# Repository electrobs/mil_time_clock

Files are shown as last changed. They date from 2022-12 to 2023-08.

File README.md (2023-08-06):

# Military Time Clock

Military Time Clock using the 89S51 microcontroller.

author: Jay Convertino

date: 2022.12.11

license: MIT (software/hardware)

IMPORTANT: No build instructions are included. All parts needed are here, you're on your own.

## Release Versions
### Current
  - v1.0.2 = Fixed time base issues with a smaller range tuning cap.

### Past
  - v1.0.1 = Sound buzz fixed with feedback bypass resistor.
  - v1.0.0 = Original Version

## Requirements
### Hardware
  - KiCad (v7.X.X)

### Software
  - sdcc compiler (4.0.0 #11528)

## Information

### Directory Listing:

  - docs
    - Datasheets: Data documents for various ICs.
    - Manual: User manual for the clock.
  - schematic: KiCad schematic of Military Time Clock, including PCB design and bill of materials.
  - model
    - FreeCAD: Any FreeCAD models used in the project.
    - Inventor: Any Autodesk Inventor 2023 models used in the project (STL included).
  - src: Any source code for the project.
    - clock_sdcc: contains make file and code for the clock project.

### Usage
  Please see the user manual on how to use the project. Build instructions really depend on how you want to build it. It uses all through hole parts and could be done with something as simple as an etch kit, PCB mill, or a PCB fab.

### Tuning
  Recommend using a platic tuning tool to adjust trimmer cap. Track the freqency at the 2.048kHz and lower pins till they all match there expected outputs (all powers of two, 1024, 512, 128 etc). Also let the device run for about 15 minutes and check. Frequency will rise by 1 to 2 hz and then stablize within the first 30 seconds, but it is wise to triple check after some time has passed.

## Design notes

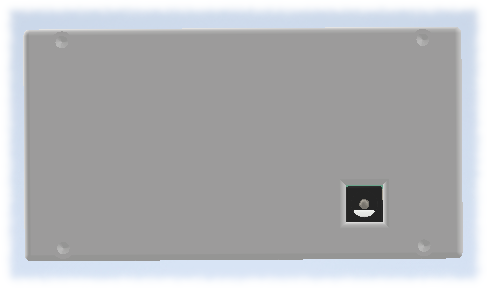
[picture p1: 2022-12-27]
model/Inventor/pics/case_rear.bmp

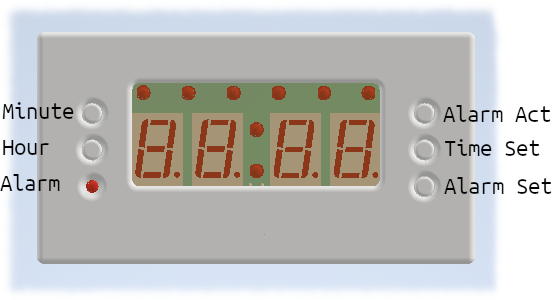
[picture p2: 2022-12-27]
model/Inventor/pics/case_front.bmp

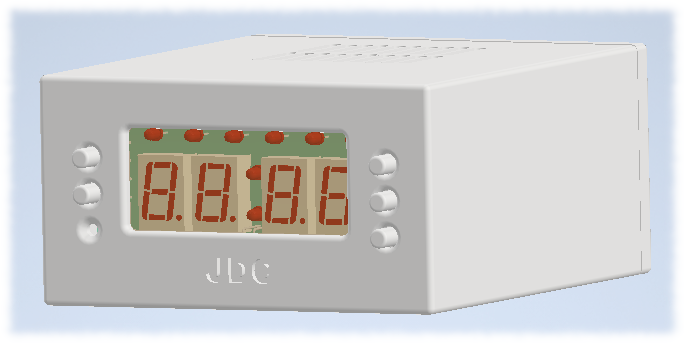
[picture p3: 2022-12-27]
model/Inventor/pics/case.bmp

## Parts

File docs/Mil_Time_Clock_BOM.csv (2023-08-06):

Date: | Tue 27 Dec 2022 05:07:47 PM EST
Component Count: | 102
Collated Components:
Item | Qty | Reference(s) | Value | Datasheet | Supplier | Manufacturer | Manufacturer Part Number | Price (Each @1) | Price (@ Quantity)
CAP CER 33PF 100V C0G/NP0 RADIAL | 1 | C1 | 33pF | https://datasheets.kyocera-avx.com/SR-Series.pdf | Digikey | KYOCERA AVX | SR151A330JAR | $0.44 | $0.44
CAP TRIMMER 2-5PF 100V TH | 1 | C2 | 6-30pF | https://media.digikey.com/pdf/Data%20Sheets/EW%20Electronics-Edmar/GKGxx015_016_Series_DS.pdf | Digikey | EW Electronics | GKG30015 | $0.97 | $0.97
CAP CER 0.1UF 100V X7S RADIAL | 14 | C3, C4, C5, C6, C7, C8, C9, C10, C17, C18, C19, C22, C23, C25 | 100nF | https://product.tdk.com/en/system/files | Digkey | TDK | FG28X7S2A104KRT06 | $0.38 | $5.32
CAP CER 18PF 100V C0G/NP0 RADIAL | 3 | C11, C12, C26 | 18pF | https://datasheets.kyocera-avx.com/SR-Series.pdf | Digkey | KYOCERA AVX | SR151A180JAR | $0.52 | $1.56
CAP ALUM 4.7UF 20% 16V RADIAL | 1 | C13 | 4.7uF | https://www.mouser.com/datasheet/2/212/KEM_A4004_ESK-1103206.pdf | Digikey | Kemet | ESK475M016AC3AA | $0.24 | $0.24
CAP CER 47PF 100V C0G RADIAL | 1 | C14 | 47nF | https://product.tdk.com/en/system/files | Digkey | TDK | FG28C0G2A470JNT06 | $0.27 | $0.27
CAP ALUM 330UF 20% 6.3V RADIAL | 2 | C15, C16 | 330uF | https://www.mouser.com/datasheet/2/212/KEM_A4004_ESK-1103206.pdf | Digikey | Kemet | ESK337M6R3AE3AA | $0.27 | $0.54
CAP CER 1000PF 100V X7R RADIAL | 1 | C20 | 1nF | https://product.tdk.com/en/system/files | Digkey | TDK | FG28X7R2A102KNT06 | $0.27 | $0.27
CAP ALUM 47UF 20% 6.3V RADIAL | 1 | C21 | 47uF | https://www.mouser.com/datasheet/2/212/KEM_A4004_ESK-1103206.pdf | Digikey | Kemet | ESK476M6R3AC3AA | $0.22 | $0.22
CAP ALUM 10UF 20% 16V RADIAL | 1 | C24 | 10uF | https://www.mouser.com/datasheet/2/212/KEM_A4004_ESK-1103206.pdf | Digikey | Kemet | ESK106M016AC3KA | $0.24 | $0.24
LED GREEN DIFFUSED 3MM ROUND T/H | 9 | D1, D2, D3, D4, D5, D6, D7, D8, D9 | LED | https://www.we-online.com/components/products/datasheet/151031VS06000.pdf | Digikey | Würth Elektronik | 151031VS06000 | $0.17 | $1.53
CONN HEADER R/A 36POS 2.54MM (CUT TO LENGTH) | 1 | J1, J4 (BOTH ARE SAME PART, BOARD TO BOARD CONNECT) | Conn_01x27 | https://multimedia.3m.com/mws/media/22446O/3mtm-100-in-pinstriphdr-295matng-length-929-series-ts0768.pdf | Digikey | 3M | 929500-01-36-RK | $3.52 | $3.52
0.1W Round Ferrite Speaker | 1 | J2 – Speaker | Speaker_Conn | https://www.jameco.com/z/45P30S-Panasonic-0-1W-Round-Ferrite-Speaker_2205561.html | Jameco | Panasonic | 45P30S | $0.69 | $0.69
DC Power Connectors Power Jack/Connector 2.1mm x 5.5mm | 1 | J3 | Barrel_Jack_Switch | https://www.gravitech.us/poja2x51.html | Mouser | Gravitech | CON-SOCJ-2155 | $1.00 | $1.00
TRANS NPN 40V 0.2A TO92-3 | 5 | Q1, Q2, Q3, Q4, Q5 | 2N3904 | https://www.onsemi.com/pdf/datasheet/pzt3904-d.pdf | Digikey | onsemi | 2N3904TFR | $0.38 | $1.90
RES 1K OHM 5% 1/4W AXIAL | 2 | R1, R2 | 1K | https://www.te.com/commerce/DocumentDelivery/DDEController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 | Digikey | TE Connectivity Passive Product | CFR16J1K0 | $0.10 | $0.20
RES 4K7 OHM 5% 1/4W AXIAL | 5 | R3, R4, R5, R6, R7 | 4k7 | https://www.te.com/commerce/DocumentDelivery/DDEController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 | Digikey | TE Connectivity Passive Product | CFR16J4K7 | $0.10 | $0.50
RES 1K OHM 5% 1/4W AXIAL | 6 | R8, R18, R30, R32, R34, R36 | 1k | https://www.te.com/commerce/DocumentDelivery/DDEController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 | Digikey | TE Connectivity Passive Product | CFR16J1K0 | $0.10 | $0.60
RES 200K OHM 5% 1/4W AXIAL | 1 | R9 | 200k | https://www.seielect.com/catalog/sei-cf_cfm.pdf | Digikey | Stackpole Electronics Inc | CF14JT200K | $0.10 | $0.10
RES 470 OHM 5% 1/4W AXIAL | 6 | R10, R11, R12, R13, R14, R21 | 470R | https://www.te.com/commerce/DocumentDelivery/DDEController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 | Digikey | TE Connectivity Passive Product | CFR16J470R | $0.10 | $0.60
RES 10M OHM 5% 1/4W AXIAL | 1 | R15 | 10M | https://www.seielect.com/catalog/sei-cf_cfm.pdf | Digikey | Stackpole Electronics Inc | CF14JT10M0 | $0.10 | $0.10
RES 1K OHM 5% 1/4W AXIAL | 1 | R16 | 1K | https://www.te.com/commerce/DocumentDelivery/DDEController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 | Digikey | TE Connectivity Passive Product | CFR16J1K0 | $0.10 | $0.10
RES 10K OHM 5% 1/4W AXIAL | 6 | R17, R20, R29, R31, R33, R35 | 10K | https://www.te.com/commerce/DocumentDelivery/DDEController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 | Digikey | TE Connectivity Passive Product | CFR16J10K | $0.10 | $0.60
RES 1K OHM 5% 1/4W AXIAL | 6 | R22, R23, R24, R25, R26, R27 | 1K | https://www.te.com/commerce/DocumentDelivery/DDEController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 | Digikey | TE Connectivity Passive Product | CFR16J1K0 | $0.10 | $0.60
RES 10 OHM 5% 1/4W AXIAL | 1 | R28 | 10R | https://www.seielect.com/catalog/sei-cf_cfm.pdf | Digikey | Stackpole Electronics Inc | CF14JT10R0 | $0.10 | $0.10
RES 100 OHM 5% 1/4W AXIAL | 7 | R37, R38, R39, R40, R41, R42, R43 | 100R | https://www.te.com/commerce/DocumentDelivery/DDEController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 | Digikey | TE Connectivity Passive Product | CFR16J100R | $0.10 | $0.70
SWITCH TACTILE SPST-NO 0.05A 12V | 5 | S1, S2, S3, S4, S5 | SPST-NO | https://sten-eswitch-13110800-production.s3.amazonaws.com/system/asset/product_line/data_sheet/144/TL1105.pdf | Digikey | E-Switch | TL1105DF160Q | $0.20 | $1.00
CONN HEADER VERT 1POS | 1 | TP1 | TestPoint | Connector Header Through Hole 1 position | Digikey | Amphenol ICC | 861400011YO2LF | $0.10 | $0.10
7 SEGMENT LED DISPLAY | 4 | U1, U2, U3, U4 | SM420561N | https://www.we-online.com/components/products/datasheet/157142V12703.pdf | Digikey | Würth Elektronik | 157142V12703 | $1.09 | $4.36
IC AMP CLASS AB MONO 700MW 8DIP | 1 | U5 | LM386 | http://www.ti.com/lit/ds/symlink/lm386.pdf | Digikey | Texas Instruments | LM386 | $1.34 | $1.34
IC MUX/DEMUX 8X1 16DIP | 1 | U6 | 74HC4051 | https://www.ti.com/general/docs/suppproductinfo.tsp?distId=10 | Digikey | Texas Instruments | CD74HC4051E | $0.78 | $0.78
IC MCU 8BIT 4KB FLASH 40DIP | 1 | U7 | AT89S51-24PU | https://ww1.microchip.com/downloads/en/DeviceDoc/doc2487.pdf | Digikey | Microchip | AT89S51-24PU | $3.63 | $3.63
IC ASYNC BIN CNTR/OSCIL 16 DIP | 1 | U9 | SN74HC4060N | https://www.ti.com/general/docs/suppproductinfo.tsp?distId=10 | Digikey | Texas Instruments | SN74HC4060N | $0.85 | $0.85
CRYSTAL 32.7680KHZ 12.5PF TH | 1 | Y1 | 32.768Khz | https://abracon.com/Resonators/AB38T.pdf | Digikey | Abracon | AB38T-32.768KHZ | $0.17 | $0.17
CRYSTAL 12.0000MHZ 18PF TH | 1 | Y2 | 12Mhz | https://www.ctscorp.com/wp-content/uploads/ATS-ATSSM.pdf | Digikey | CTS-Frequency Control | ATS120B-E | $0.36 | $0.36
AC/DC WALL MOUNT ADAPTER 5V 2.5W 2.1x5.5mm Barrel Plug | 1 | N/A | PSU | https://www.nteinc.com/acdc_adapters/adapters_01.pdf | Digikey | NTE | 57-5D-500-4 | $10.01 | $10.01
Total Cost: | $45.11

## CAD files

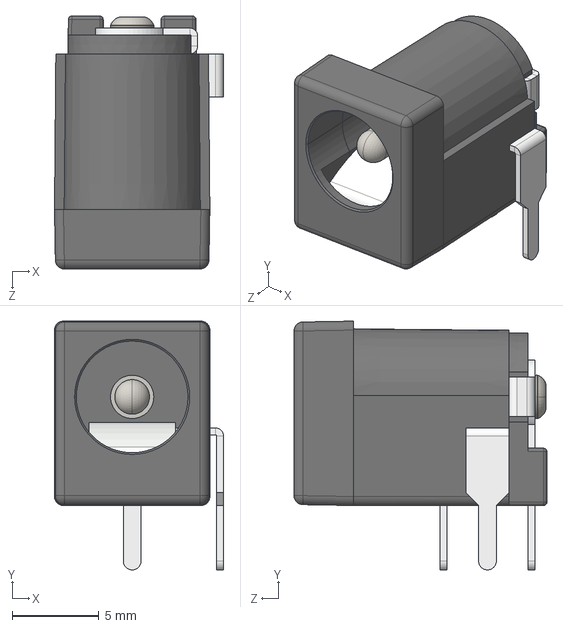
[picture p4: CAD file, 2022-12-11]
model/dc-power-jack/DC Power Jack 5.5mm x 2.1mm.STEP
9.77 x 14.4 x 14.6 mm

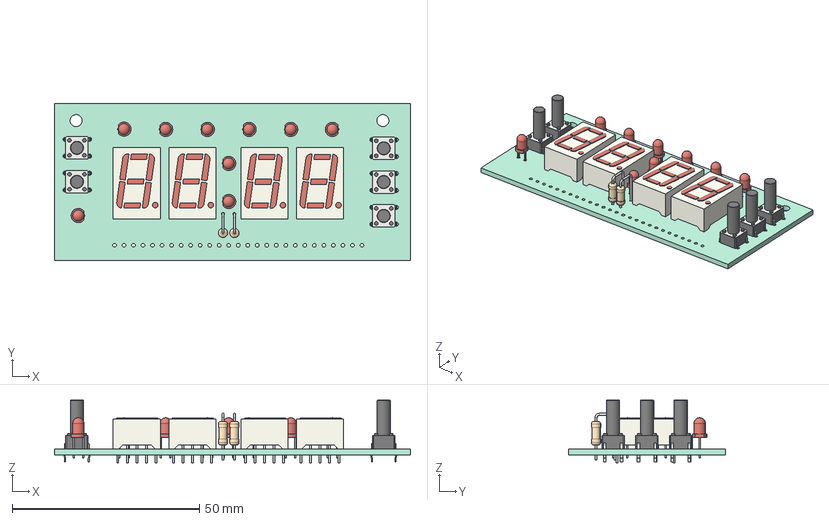
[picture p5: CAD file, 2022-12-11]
model/FreeCAD/DISPLAY_pcb-LED_DISPLAY_BOARD.step
95.0 x 41.9 x 16.8 mm
Local_CS_403d
Pcb_403d
S3_SW_PUSH_6mm_h13mm_974d04aa10fd x 5
R1_R_Axial_DIN0207_L63mm_D25mm_P508mm_Vertical_1518434c2957 x 2
U1_7SegmentLED_LTS6760_LTS6780_943fd5891115 x 4
D7_LED_D3.0mm_359ad34fe5f4 x 9

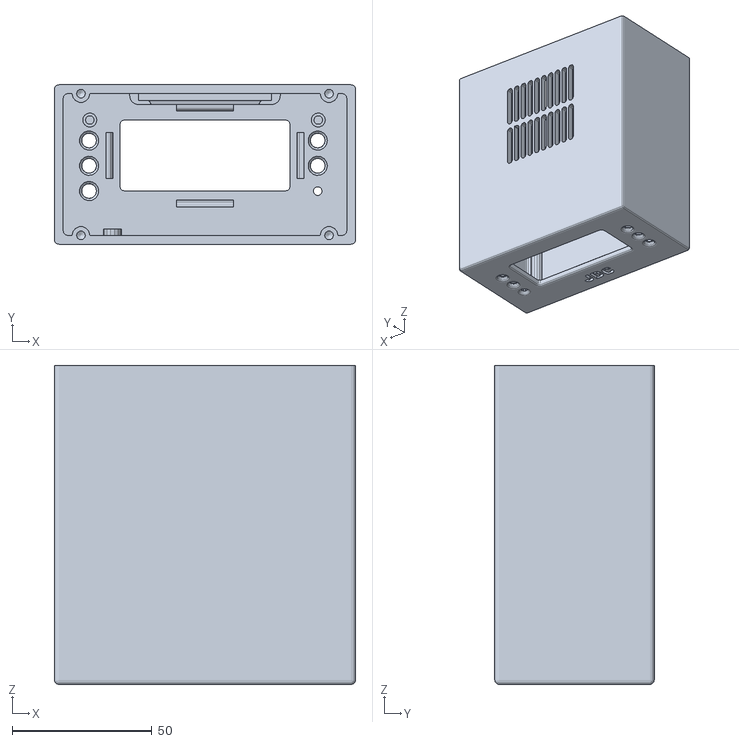
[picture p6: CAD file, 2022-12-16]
model/Inventor/Case_Front.stl
107.9 x 57.2 x 114.3

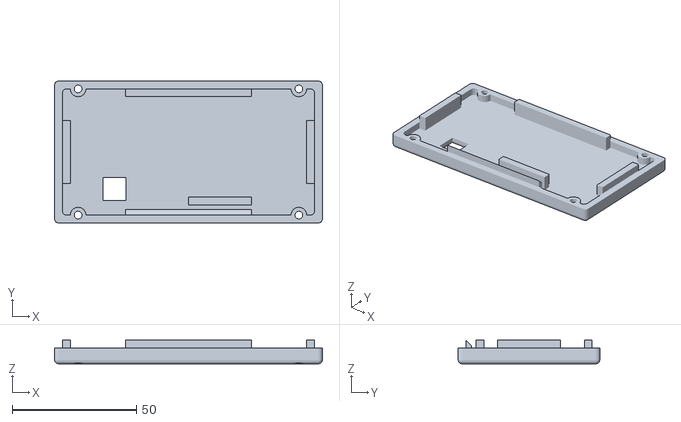
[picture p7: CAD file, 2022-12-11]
model/Inventor/Case_Rear.stl
107.9 x 57.2 x 9.52

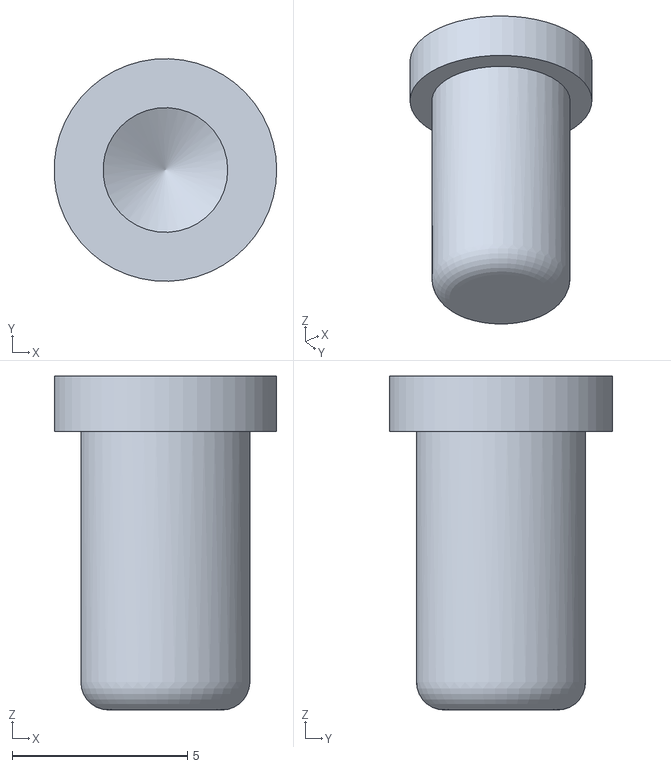
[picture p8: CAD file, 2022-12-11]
model/Inventor/button.stl
6.34 x 6.35 x 9.52

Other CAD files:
model/Inventor/CASE_ASSM/OldVersions/case.0015.iam
model/Inventor/CASE_ASSM/case.iam
model/Inventor/Case_Front.dwg
model/Inventor/Case_Front.ipt
model/Inventor/Case_Rear.dwg
model/Inventor/Case_Rear.ipt
model/Inventor/Case_lens.ipt
model/Inventor/DISPLAY_IPT/Board_Geoms_403d.iam
model/Inventor/DISPLAY_IPT/D7_LED_D3.0mm_359ad34fe5f4.ipt
model/Inventor/DISPLAY_IPT/DISPLAY_pcb-LED_DISPLAY_BOARD.iam
model/Inventor/DISPLAY_IPT/Pcb_403d.ipt
model/Inventor/DISPLAY_IPT/R1_R_Axial_DIN0207_L63mm_D25mm_P508mm_Vertical_1518434c2957.ipt
model/Inventor/DISPLAY_IPT/S3_SW_PUSH_6mm_h13mm_974d04aa10fd.ipt
model/Inventor/DISPLAY_IPT/Step_Models_403d.iam
model/Inventor/DISPLAY_IPT/Top_403d.iam
model/Inventor/DISPLAY_IPT/U1_7SegmentLED_LTS6760_LTS6780_943fd5891115.ipt
model/Inventor/MCU_IPT/Board_Geoms_bc71.iam
model/Inventor/MCU_IPT/C10_C_Disc_D30mm_W20mm_P250mm_fe13f3843ca1.ipt
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

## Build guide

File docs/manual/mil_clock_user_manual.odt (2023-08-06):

JDC

Military Time Alarm Clock

2022-12 v1.0.2


# Introduction

## Purpose

The military time alarm clock is a standard alarm clock that uses military time for the display. The clock includes one alarm that is set in military time. The clock is designed using the state-of-the-80’s hardware for user serviceability along with a full open source design under the MIT license.

Inside the clock is a 8051 micro-controller (ATMEL 89S51 variant) to power the device. This is a widely used part that is still being produced and used in multiple products as its core controller. The time base clock is a state-of-the-cmos 4060. The 4060 is a divider that has some of its unused clocks fed to a 4051 selection chip with an output to a LM386 amplifier. This gives the alarm its distinctive sound that cycles through all the tones being fed to it.

# Usage

## Setup The Clock

1. Remove the clock from its packaging.
2. Check that all the parts are included.
  - One clock
  - One 5 volt power adapter
3. Set the clock near a wall outlet that the power adapter can reach.
  - WARNING DO NOT PUT STRESS ON THE CORD.
4. Place the clock on a stable surface to prevent falling.


Figure 1.0

## First Time Power On

1. After setting up the clock, plug the power adapter into the wall.
2. Plug the barrel jack of the power adapter into the rear connector of the clock.
  - This will insert about half an inch into the device, this is normal.
  - See figure 1.0 on the previous page.
3. The clock will take approximately 2 seconds to power on.
4. Once powered on it will flash 00:00 every other second.
5. This will continue till TIME SET is pressed.
  - See figure 1.1 on the next page.
6. The clock is now ready for operation.


  Figure 1.1

## Setting The Time

1. Once the clock is powered on, time set can be performed.
2. Press and hold the TIME SET button, while performing the following actions. See figure 1.1 on previous page.
  a. Press the minute button to increment the minutes till the desired number is displayed.
    - Can be pressed and held for speed increment, tapped for single increments.
    - Minutes will roll over from 59 to 0 and will not increment hours.
  b. Press the hour button to increment the hours till the desired number is displayed.
    - Can be pressed and held for speed increment, tapped for single increments.
    - Hours will roll over from 23 to 0.
3. Let go of the TIME SET button to complete time set.

## Sync Time

  To sync the time with another clock follow this procedure.
    1. Set the time to one minute ahead of the clock you would like to sync to.
    2. Hold the TIME SET button till the clock to sync to changes to that minute, and let go.
      - The clock will start from 0 seconds (seconds are reset) whenever TIME SET is pressed.

## Setting The Alarm

1. With the time set, the alarm can be set in a similar manner.
2. Press and hold the ALARM SET button, while performing the following actions. See figure 1.1 on page 7.
  a. Press the minute button to increment the minutes till the desired number is displayed.
    - Can be pressed and held for speed increment, tapped for single increments.
    - Minutes will roll over from 59 to 0 and will not increment hours.
  b. Press the hour button to increment the hours till the desired number is displayed.
    - Can be pressed and held for speed increment, tapped for single increments.
    - Hours will roll over from 23 to 0.
3. Let go of the ALARM SET button to complete alarm set.

## Activating The Alarm

  The alarm is activated by pressing the ALARM ACT button.
  - See figure 1.1 on page 7.
  - Pressing and holding will only toggle the alarm once.
  - When the alarm LED is on, the alarm is on.
  - When the alarm LED is off, the alarm is off.

## Alarm Duration

When the alarm is reached, it will stay active for one minute without intervention. Alarm can be shut off early by pressing the ALARM ACT button.

# Technical Data

## Specifications

- POWER: 5 volt DC at 500 mA max. Center Positive.
- Audio output: 325 mW Max
- Time Display: Green 7 segment LED, with 6 Binary seconds LED (0 to 59)
- Micro-controller: 89S51
- Case: ABS Plastic

## Schematic

The following pages contain the schematic for the device.

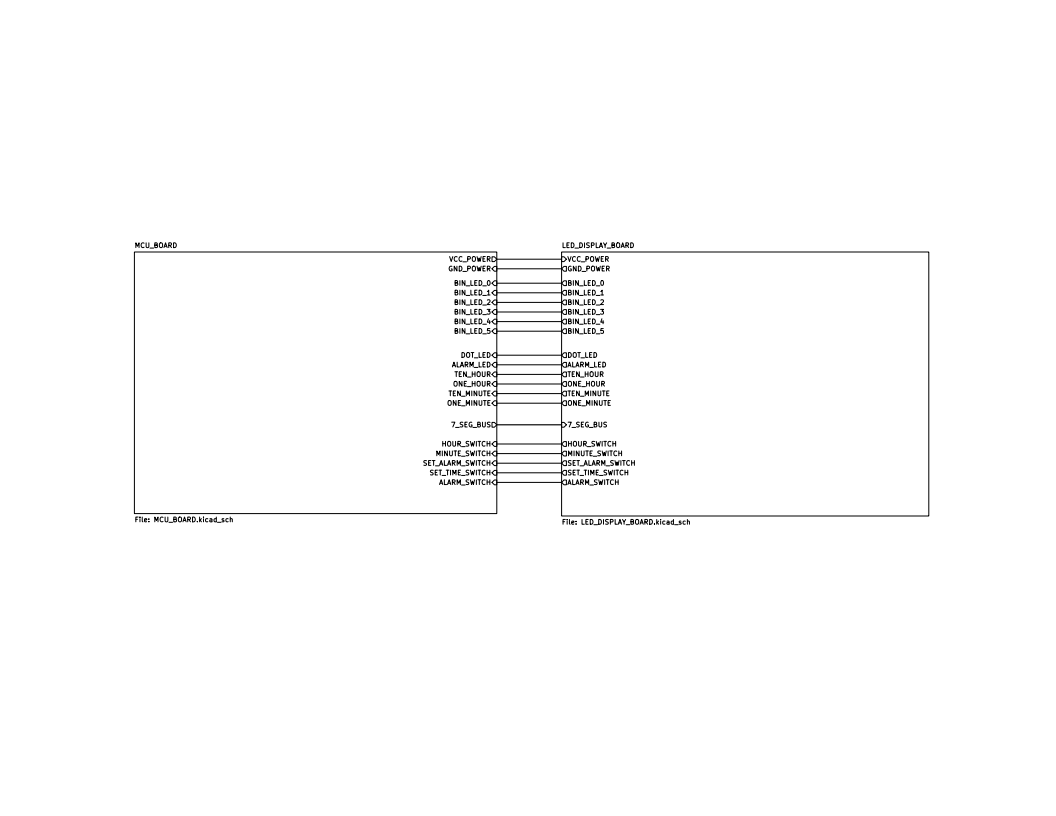
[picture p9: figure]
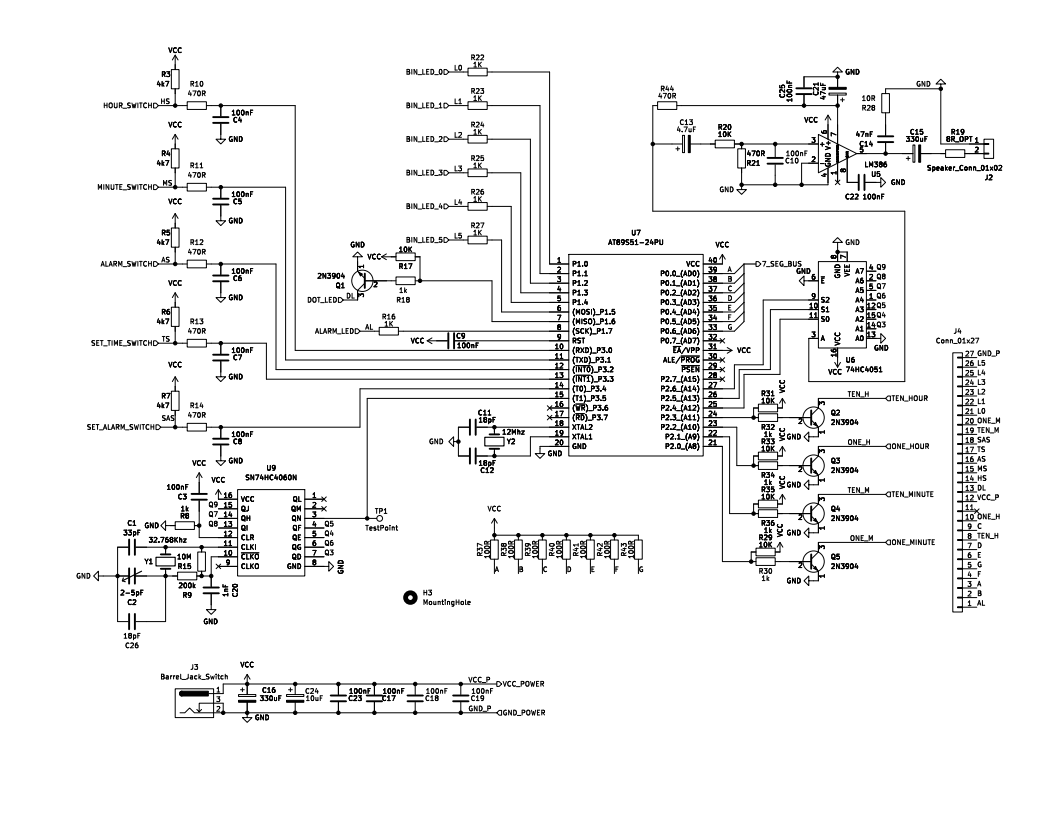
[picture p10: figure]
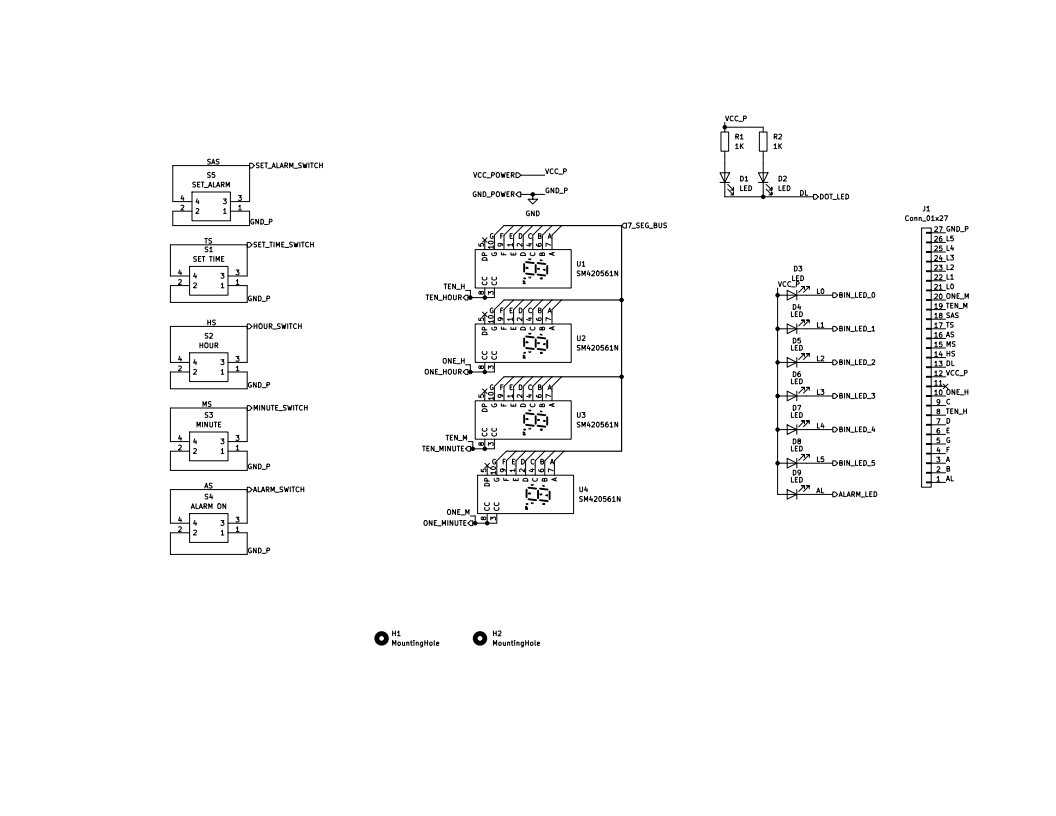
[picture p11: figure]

## CAD

The following pages contain the CAD for the device. Dimensions are not complete, and all are in inches.

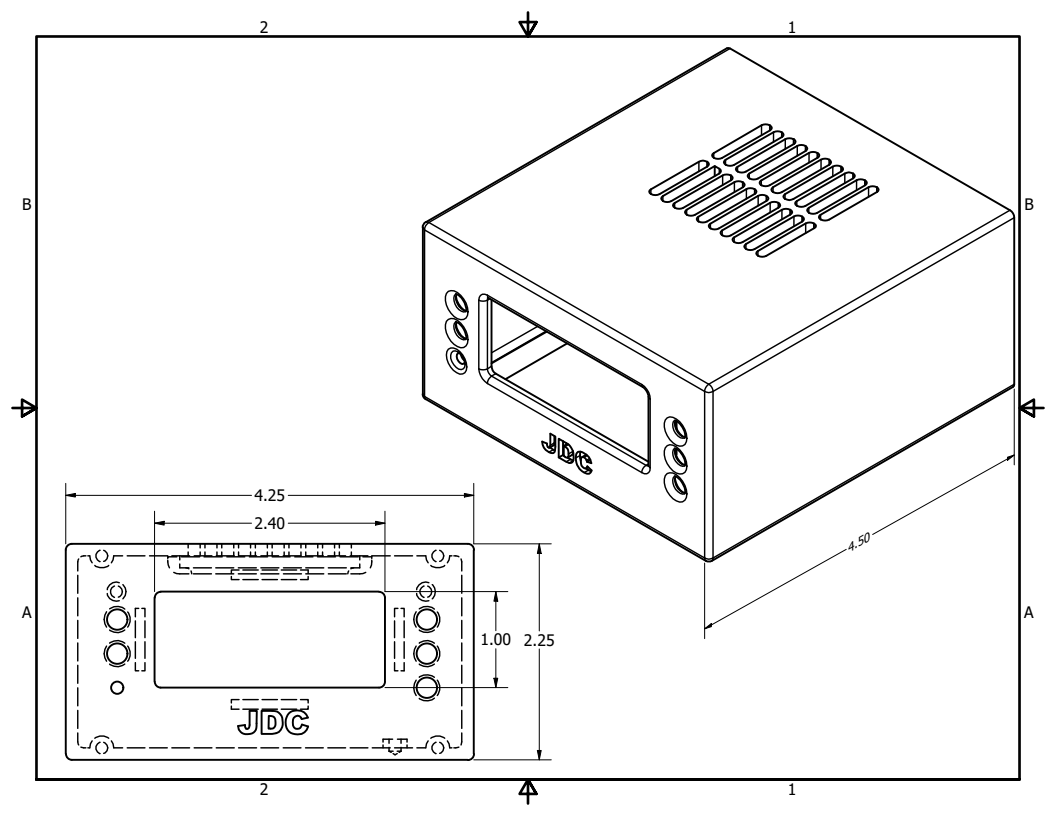
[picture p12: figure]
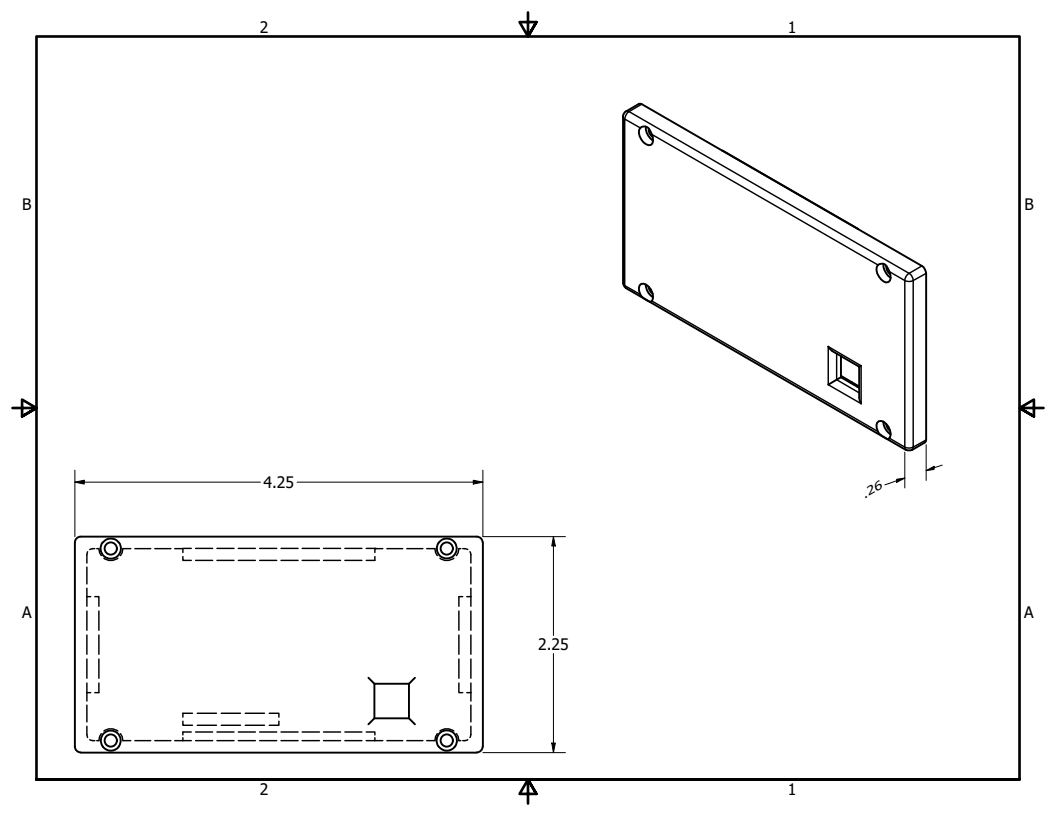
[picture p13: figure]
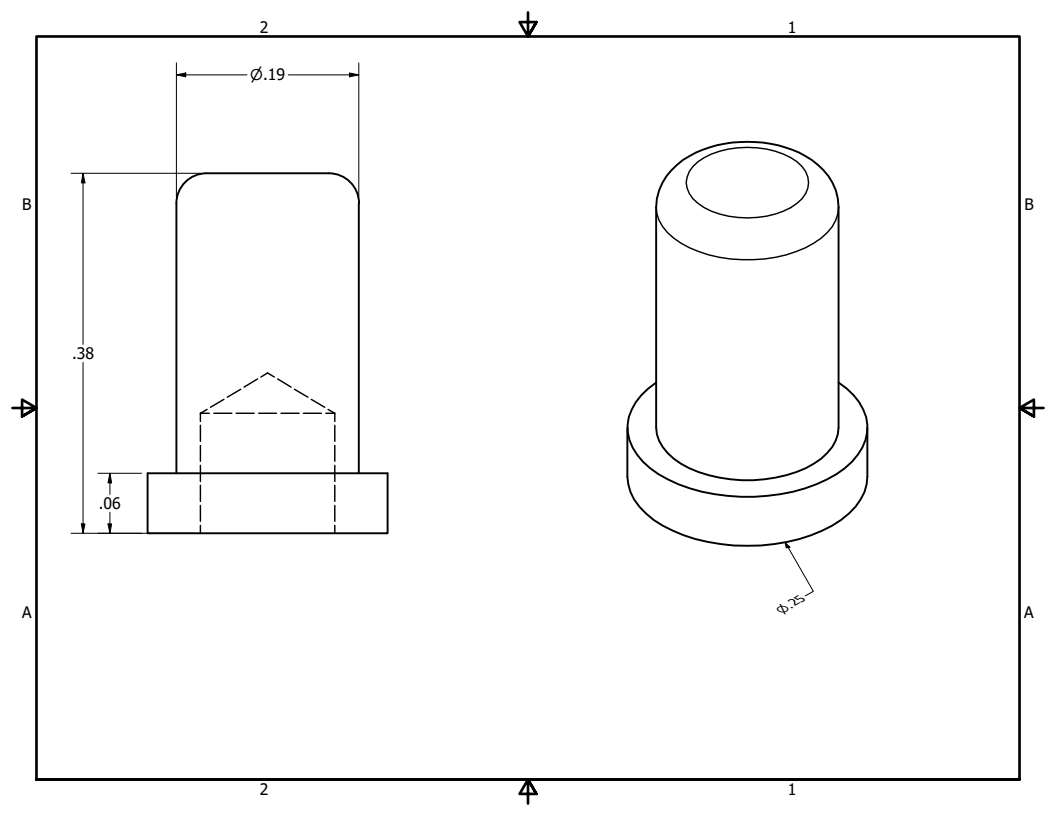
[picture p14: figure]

## Code

The following pages contain the C code for the device. They are sideways for proper formatting.

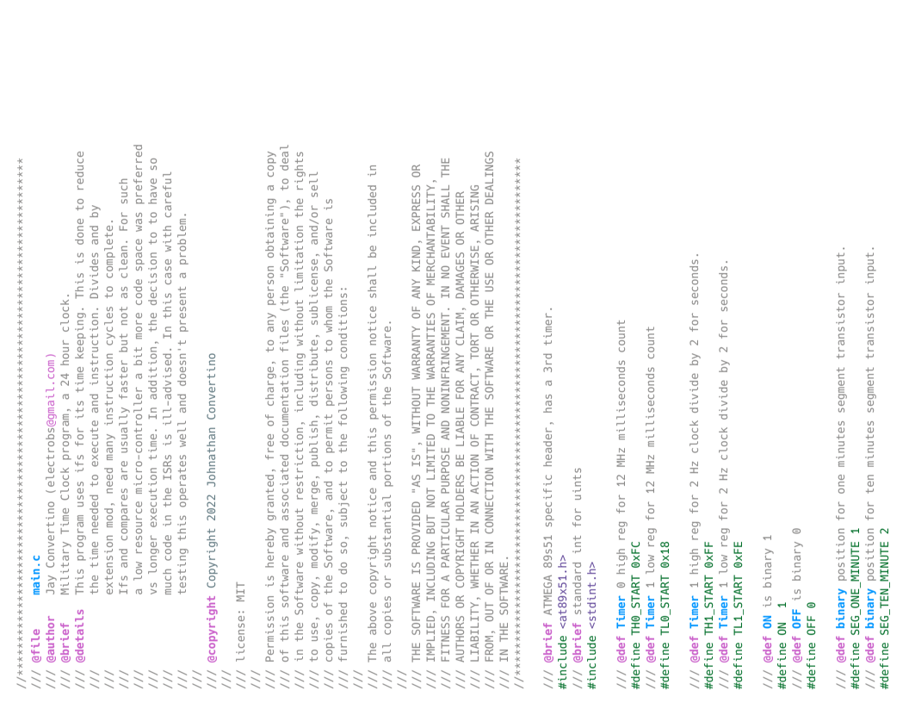
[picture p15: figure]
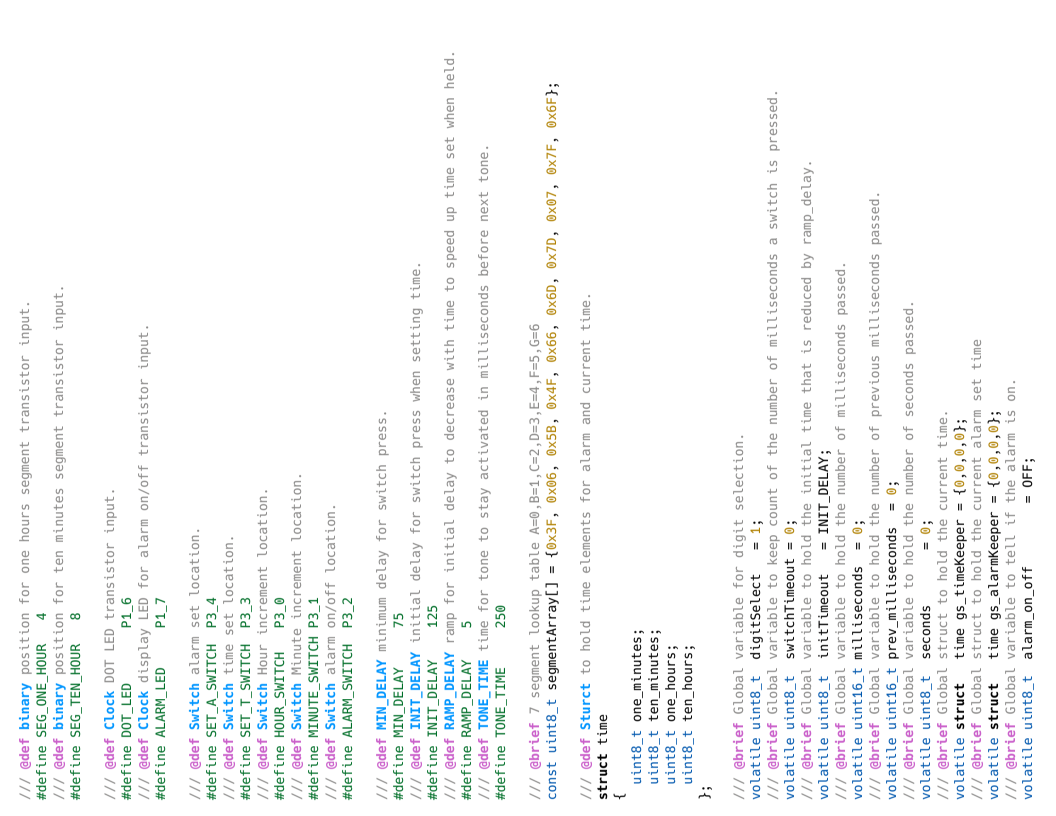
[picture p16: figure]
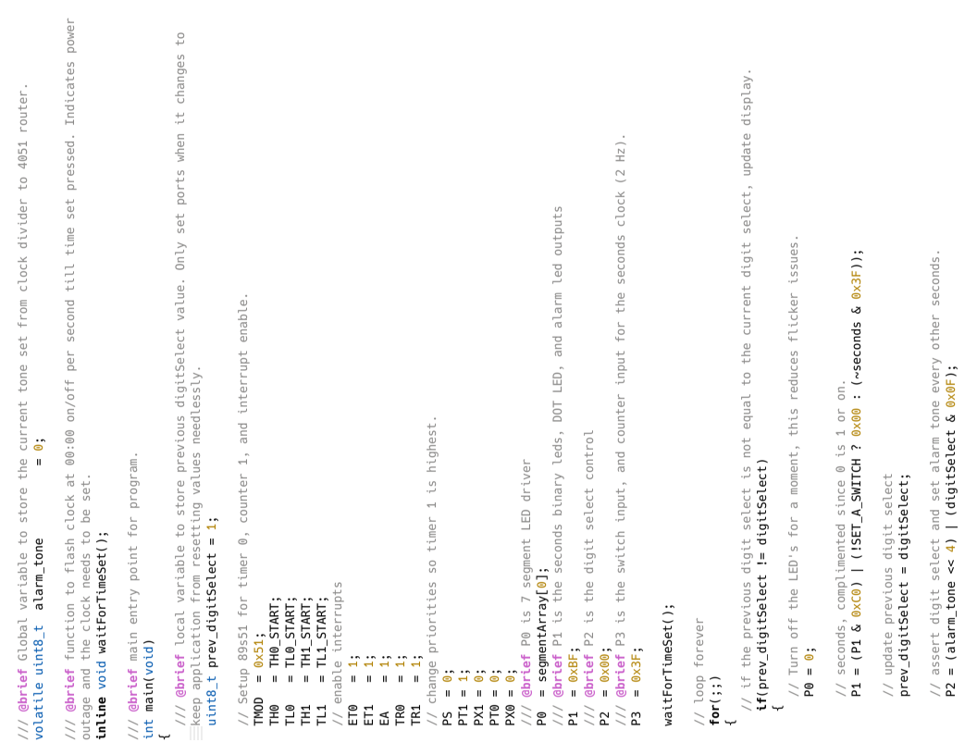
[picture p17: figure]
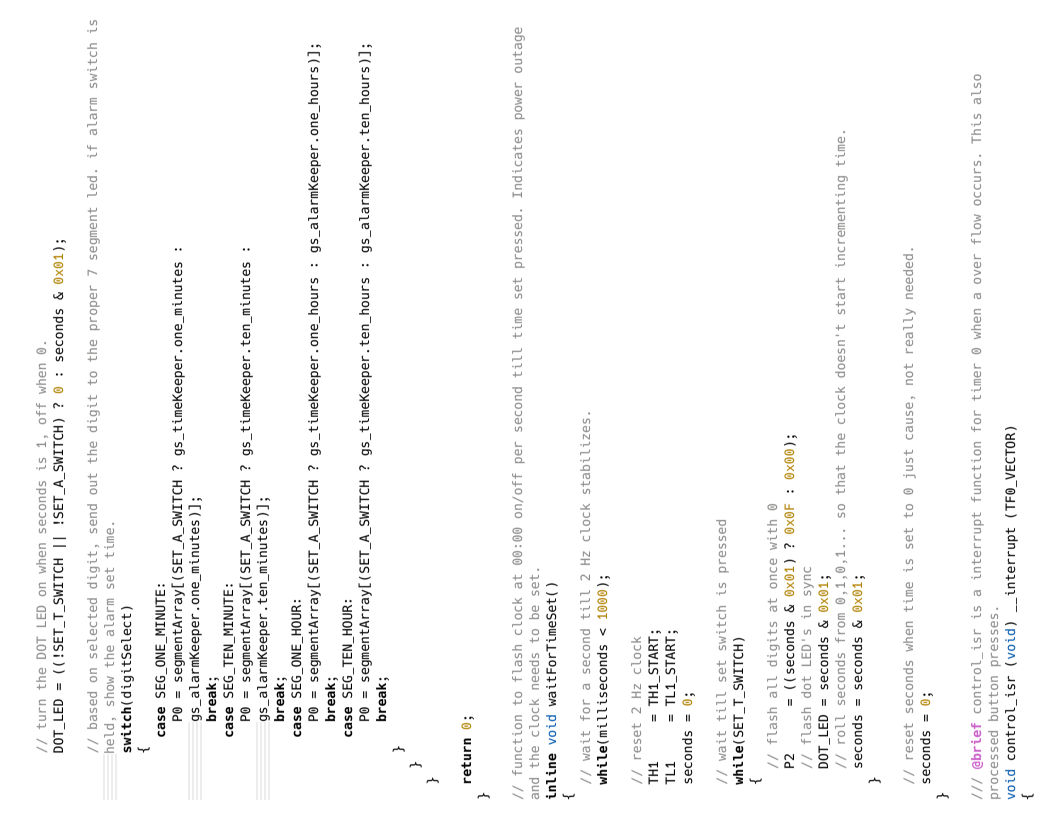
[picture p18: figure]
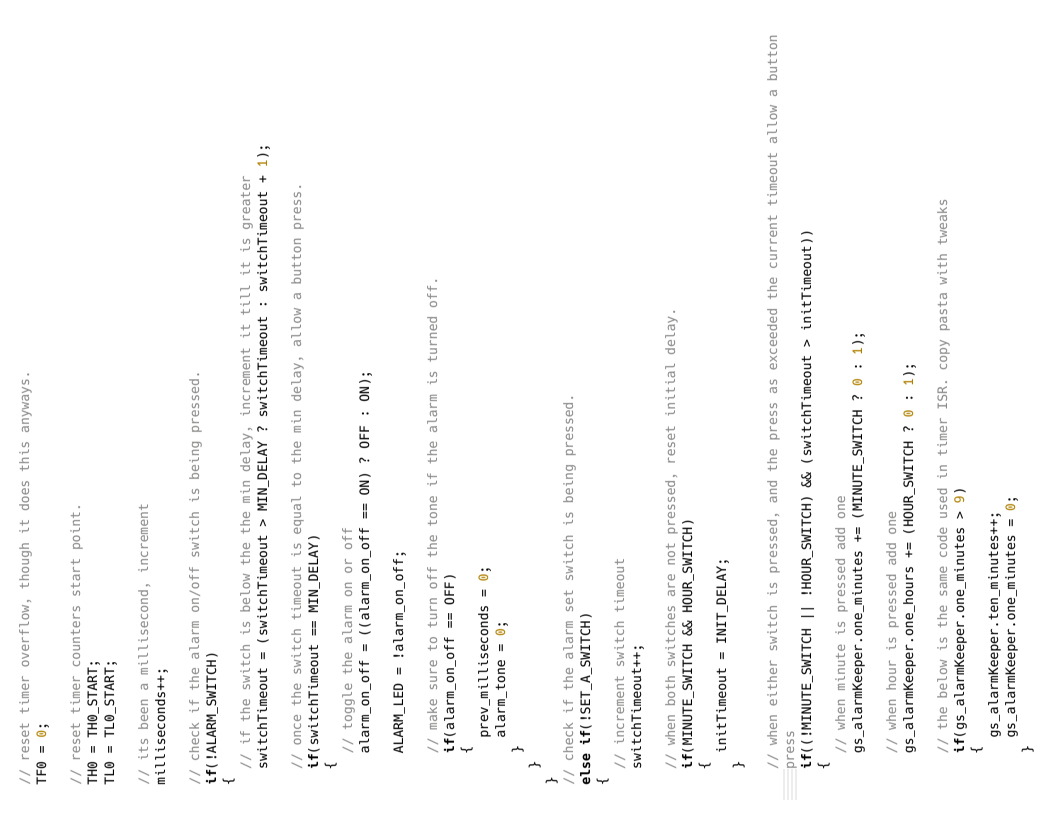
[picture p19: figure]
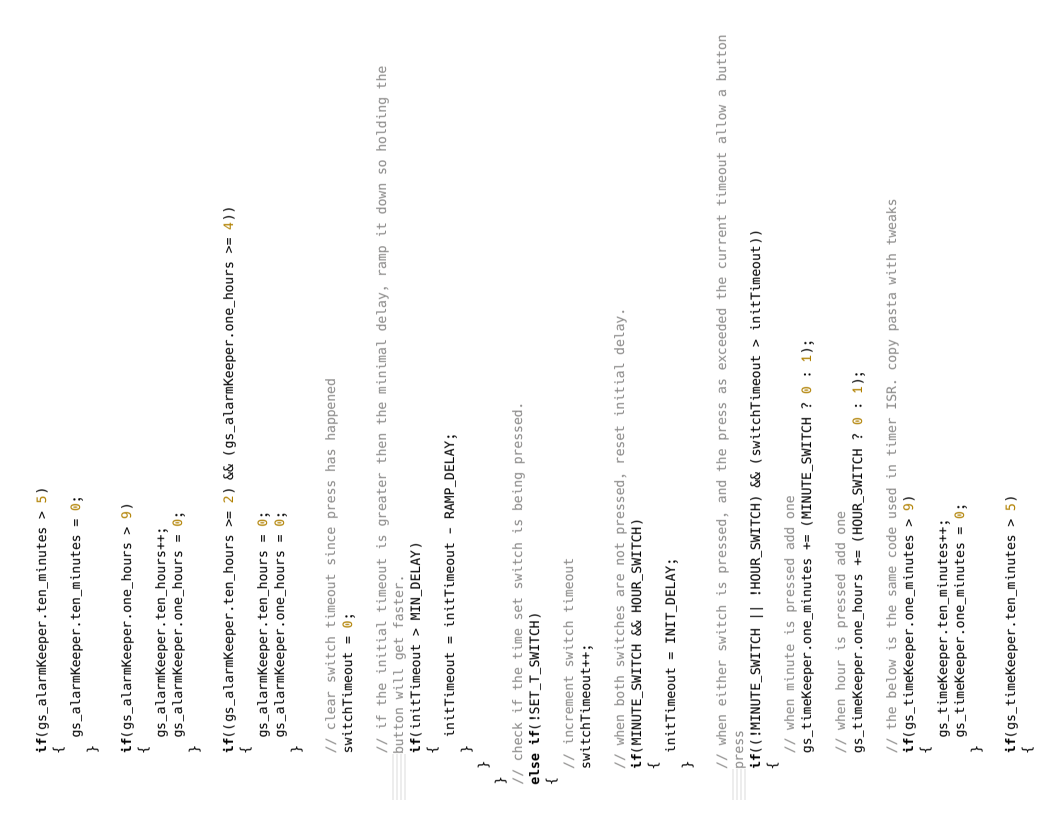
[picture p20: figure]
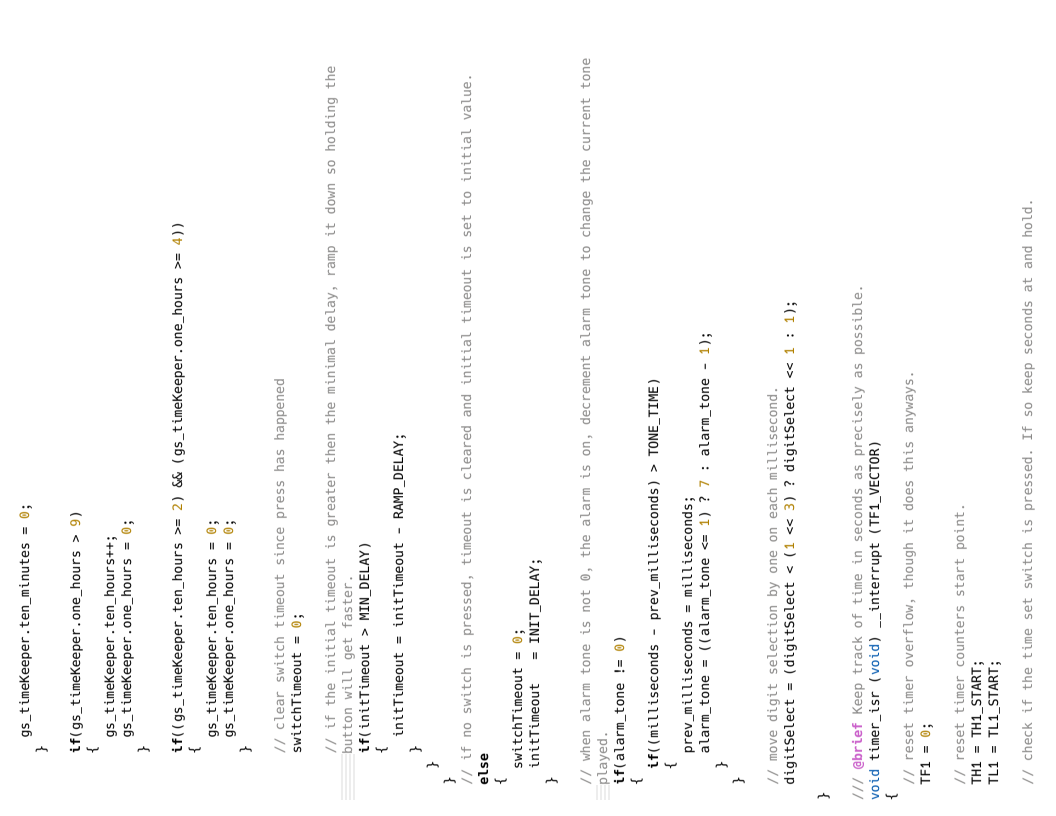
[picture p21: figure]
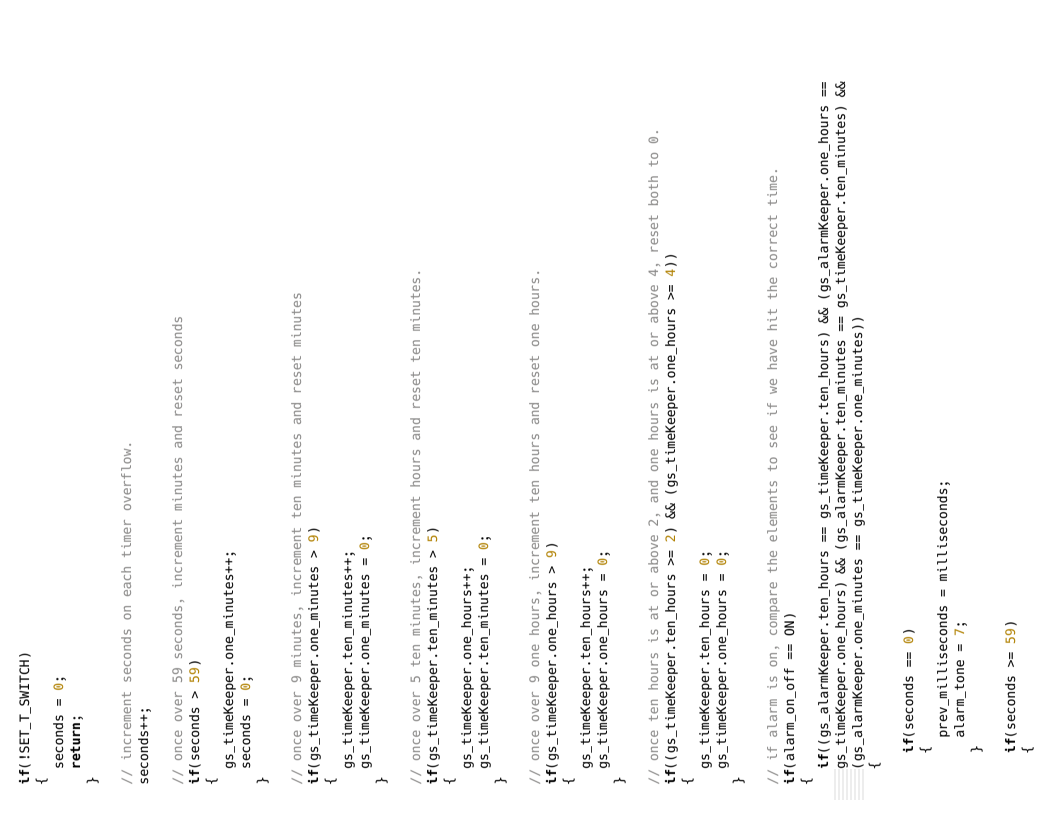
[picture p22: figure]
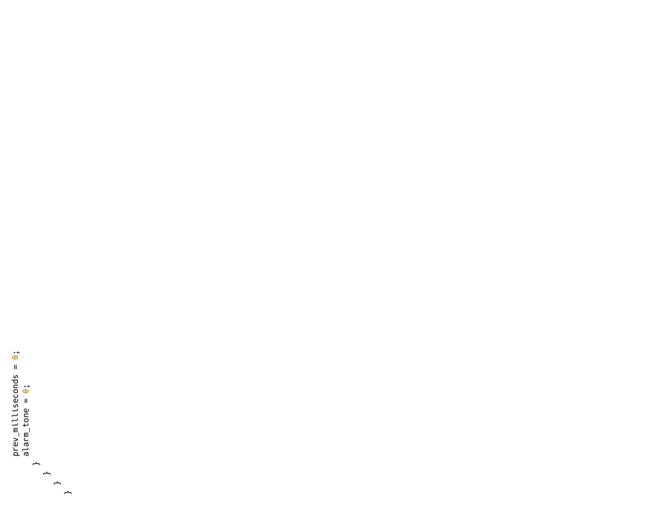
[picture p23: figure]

JDC

Military Time Alarm Clock

2022-12

v1.0.2

Change Log:

v1.0.2 = Fixed time base issues with a smaller range tuning cap.

v1.0.1 = Sound buzz fixed with feedback bypass resistor.

v1.0.0 = Original Version

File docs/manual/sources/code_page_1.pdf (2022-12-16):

//*****************************************************************************
/// @file | main.c
/// @author | Jay Convertino (electrobs@gmail.com)
/// @brief | Military Time Clock program, a 24 hour clock.
/// @details This program uses ifs for its time keeping. This is done to reduce
/// | the time needed to execute and instruction. Divides and by
/// | extension mod, need many instruction cycles to complete.
/// | Ifs and compares are usually faster but not as clean. For such
/// | a low resource micro-controller a bit more code space was preferred
/// | vs longer execution time. In addition, the decision to to have so
/// | much code in the ISRs is ill-advised. In this case with careful
/// | testing this operates well and doesn't present a problem.
///
/// @copyright Copyright 2022 Johnathan Convertino
///
/// license: MIT
///
/// Permission is hereby granted, free of charge, to any person obtaining a copy /// of this software and associated documentation files (the "Software"), to deal /// in the Software without restriction, including without limitation the rights /// to use, copy, modify, merge, publish, distribute, sublicense, and/or sell /// copies of the Software, and to permit persons to whom the Software is
/// furnished to do so, subject to the following conditions:
///
/// The above copyright notice and this permission notice shall be included in /// all copies or substantial portions of the Software.
///
/// THE SOFTWARE IS PROVIDED "AS IS", WITHOUT WARRANTY OF ANY KIND, EXPRESS OR /// IMPLIED, INCLUDING BUT NOT LIMITED TO THE WARRANTIES OF MERCHANTABILITY, /// FITNESS FOR A PARTICULAR PURPOSE AND NONINFRINGEMENT. IN NO EVENT SHALL THE /// AUTHORS OR COPYRIGHT HOLDERS BE LIABLE FOR ANY CLAIM, DAMAGES OR OTHER
/// LIABILITY, WHETHER IN AN ACTION OF CONTRACT, TORT OR OTHERWISE, ARISING /// FROM, OUT OF OR IN CONNECTION WITH THE SOFTWARE OR THE USE OR OTHER DEALINGS /// IN THE SOFTWARE.
//*****************************************************************************

/// @brief ATMEGA 89s51 specific header, has a 3rd timer.
#include <at89x51.h>

/// @brief standard int for uints
#include <stdint.h>

/// @def Timer 0 high reg for 12 MHz milliseconds count #define TH0_START 0xFC
/// @def Timer 1 low reg for 12 MHz milliseconds count
#define TL0_START 0x18

/// @def Timer 1 high reg for 2 Hz clock divide by 2 for seconds. #define TH1_START 0xFF
/// @def Timer 1 low reg for 2 Hz clock divide by 2 for seconds. #define TL1_START 0xFE

/// @def ON is binary 1
#define ON 1

/// @def OFF is binary 0
#define OFF 0

/// @def binary position for one minutes segment transistor input. #define SEG_ONE_MINUTE 1
/// @def binary position for ten minutes segment transistor input. #define SEG_TEN_MINUTE 2

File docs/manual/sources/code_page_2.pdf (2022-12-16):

/// @def binary position for one hours segment transistor input. #define SEG_ONE_HOUR 4
/// @def binary position for ten minutes segment transistor input. #define SEG_TEN_HOUR 8

/// @def Clock DOT LED transistor input.
#define DOT_LED | P1_6

/// @def Clock display LED for alarm on/off transistor input. #define ALARM_LED P1_7

/// @def Switch alarm set location.
#define SET_A_SWITCH P3_4

/// @def Switch time set location. #define SET_T_SWITCH P3_3
/// @def Switch Hour increment location. #define HOUR_SWITCH P3_0
/// @def Switch Minute increment location. #define MINUTE_SWITCH P3_1
/// @def Switch alarm on/off location.
#define ALARM_SWITCH P3_2

/// @def MIN_DELAY minimum delay for switch press.
#define MIN_DELAY 75

/// @def INIT_DELAY initial delay for switch press when setting time.
#define INIT_DELAY 125

/// @def RAMP_DELAY ramp for initial delay to decrease with time to speed up time set when held. #define RAMP_DELAY 5
/// @def TONE_TIME time for tone to stay activated in milliseconds before next tone.
#define TONE_TIME 250

/// @brief 7 segment lookup table A=0,B=1,C=2,D=3,E=4,F=5,G=6
const uint8_t segmentArray[] = {0x3F, 0x06, 0x5B, 0x4F, 0x66, 0x6D, 0x7D, 0x07, 0x7F, 0x6F};

/// @def Sturct to hold time elements for alarm and current time.
struct time
{
uint8_t one_minutes;
uint8_t ten_minutes;
uint8_t one_hours;
uint8_t ten_hours;
};

/// @brief Global variable for digit selection.
volatile uint8_t digitSelect = 1;
/// @brief Global variable to keep count of the number of milliseconds a switch is pressed. volatile uint8_t switchTimeout = 0;
/// @brief Global variable to hold the initial time that is reduced by ramp_delay. volatile uint8_t initTimeout = INIT_DELAY;
/// @brief Global variable to hold the number of milliseconds passed.
volatile uint16_t milliseconds = 0;
/// @brief Global variable to hold the number of previous milliseconds passed. volatile uint16_t prev_milliseconds = 0;
/// @brief Global variable to hold the number of seconds passed.
volatile uint8_t seconds | = 0;
/// @brief Global struct to hold the current time.
volatile struct time gs_timeKeeper = {0,0,0,0};
/// @brief Global struct to hold the current alarm set time volatile struct time gs_alarmKeeper = {0,0,0,0};
/// @brief Global variable to tell if the alarm is on.
volatile uint8_t alarm_on_off | = OFF;

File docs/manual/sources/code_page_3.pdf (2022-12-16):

/// @brief Global variable to store the current tone set from clock divider to 4051 router.
volatile uint8_t alarm_tone | = 0;

/// @brief function to flash clock at 00:00 on/off per second till time set pressed. Indicates power outage and the clock needs to be set.
inline void waitForTimeSet();

/// @brief main entry point for program.
int main(void)
{
/// @brief local variable to store previous digitSelect value. Only set ports when it changes to keep application from resetting values needlessly.
uint8_t prev_digitSelect = 1;

// Setup 89s51 for timer 0, counter 1, and interrupt enable.
TMOD = 0x51;
TH0 | = TH0_START;
TL0 | = TL0_START;
TH1 | = TH1_START;
TL1 | = TL1_START;
// enable interrupts
ET0 | = 1;
ET1 | = 1;
EA | = 1;
TR0 | = 1;
TR1 | = 1;
// change priorities so timer 1 is highest. PS = 0;
PT1 = 1;
PX1 = 0;
PT0 = 0;
PX0 = 0;
/// @brief P0 is 7 segment LED driver
P0 = segmentArray[0];
/// @brief P1 is the seconds binary leds, DOT LED, and alarm led outputs P1 = 0xBF;
/// @brief P2 is the digit select control
P2 = 0x00;
/// @brief P3 is the switch input, and counter input for the seconds clock (2 Hz). P3 = 0x3F;

waitForTimeSet();

// loop forever
for(;;)
{
// if the previous digit select is not equal to the current digit select, update display. if(prev_digitSelect != digitSelect)
{
// Turn off the LED's for a moment, this reduces flicker issues.
P0 = 0;

// seconds, complimented since 0 is 1 or on.
P1 = (P1 & 0xC0) | (!SET_A_SWITCH ? 0x00 : (~seconds & 0x3F));

// update previous digit select
prev_digitSelect = digitSelect;

// assert digit select and set alarm tone every other seconds.
P2 = (alarm_tone << 4) | (digitSelect & 0x0F);

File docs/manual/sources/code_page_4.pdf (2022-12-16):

// turn the DOT LED on when seconds is 1, off when 0.
DOT_LED = ((!SET_T_SWITCH || !SET_A_SWITCH) ? 0 : seconds & 0x01);

// based on selected digit, send out the digit to the proper 7 segment led. if alarm switch is held, show the alarm set time.
switch(digitSelect)
{
case SEG_ONE_MINUTE:
P0 = segmentArray[(SET_A_SWITCH ? gs_timeKeeper.one_minutes : gs_alarmKeeper.one_minutes)];
break;
case SEG_TEN_MINUTE:
P0 = segmentArray[(SET_A_SWITCH ? gs_timeKeeper.ten_minutes : gs_alarmKeeper.ten_minutes)];
break;
case SEG_ONE_HOUR:
P0 = segmentArray[(SET_A_SWITCH ? gs_timeKeeper.one_hours : gs_alarmKeeper.one_hours)]; break;
case SEG_TEN_HOUR:
P0 = segmentArray[(SET_A_SWITCH ? gs_timeKeeper.ten_hours : gs_alarmKeeper.ten_hours)]; break;
}
}
}

return 0;
}

// function to flash clock at 00:00 on/off per second till time set pressed. Indicates power outage and the clock needs to be set.
inline void waitForTimeSet()
{
// wait for a second till 2 Hz clock stabilizes. while(milliseconds < 1000);

// reset 2 Hz clock
TH1 | = TH1_START;
TL1 | = TL1_START;
seconds = 0;

// wait till set switch is pressed while(SET_T_SWITCH)
{
// flash all digits at once with 0
P2 | = ((seconds & 0x01) ? 0x0F : 0x00);
// flash dot LED's in sync
DOT_LED = seconds & 0x01;
// roll seconds from 0,1,0,1... so that the clock doesn't start incrementing time. seconds = seconds & 0x01;
}

// reset seconds when time is set to 0 just cause, not really needed.
seconds = 0;
}

/// @brief control_isr is a interrupt function for timer 0 when a over flow occurs. This also processed button presses.
void control_isr (void) __interrupt (TF0_VECTOR)
{

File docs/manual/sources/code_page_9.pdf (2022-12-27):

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
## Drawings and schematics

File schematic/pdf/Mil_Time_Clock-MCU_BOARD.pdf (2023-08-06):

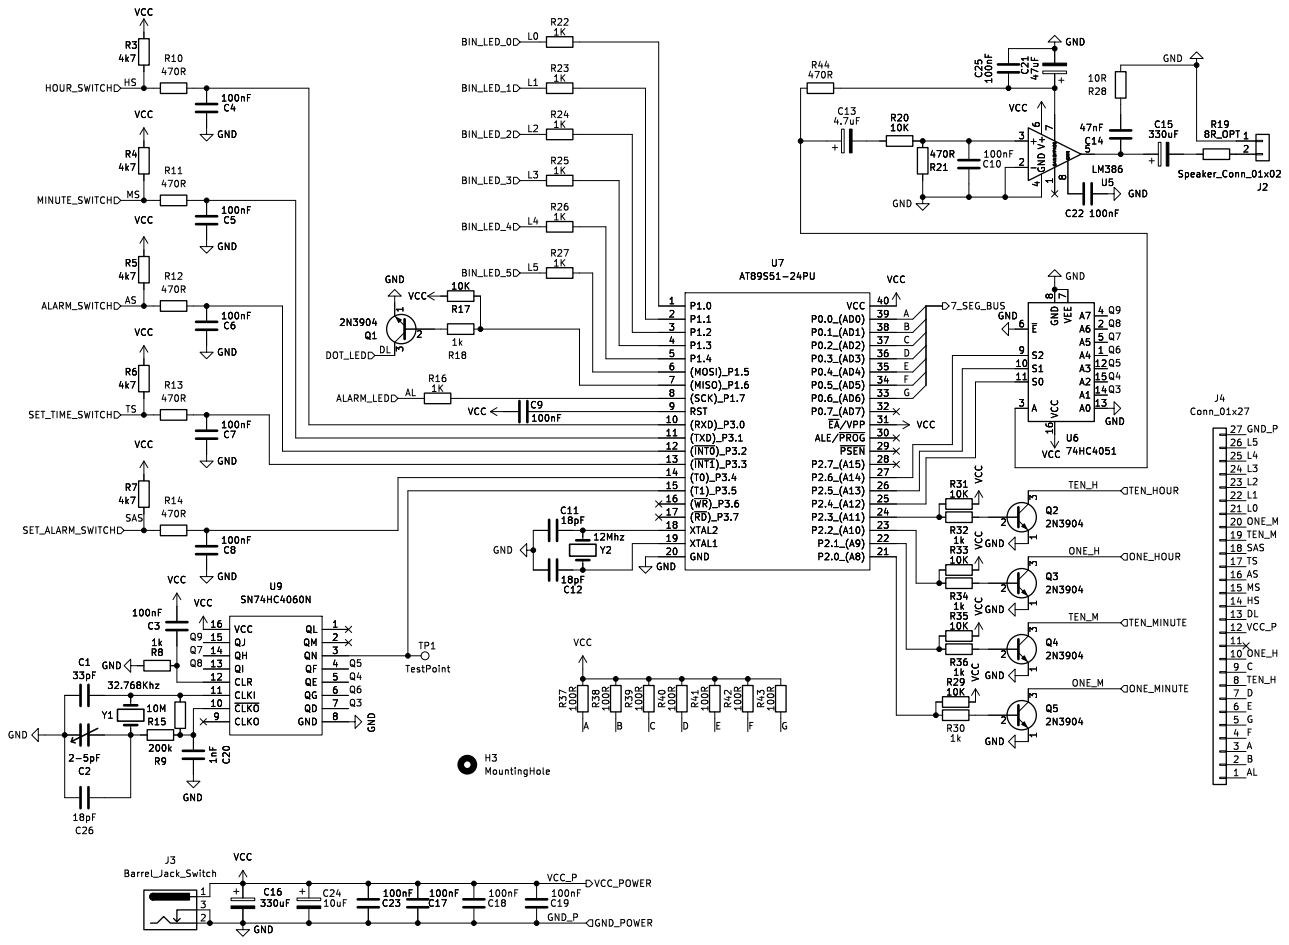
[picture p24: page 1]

3 GND VCC GND GND GND Q4
2N3904 VCC

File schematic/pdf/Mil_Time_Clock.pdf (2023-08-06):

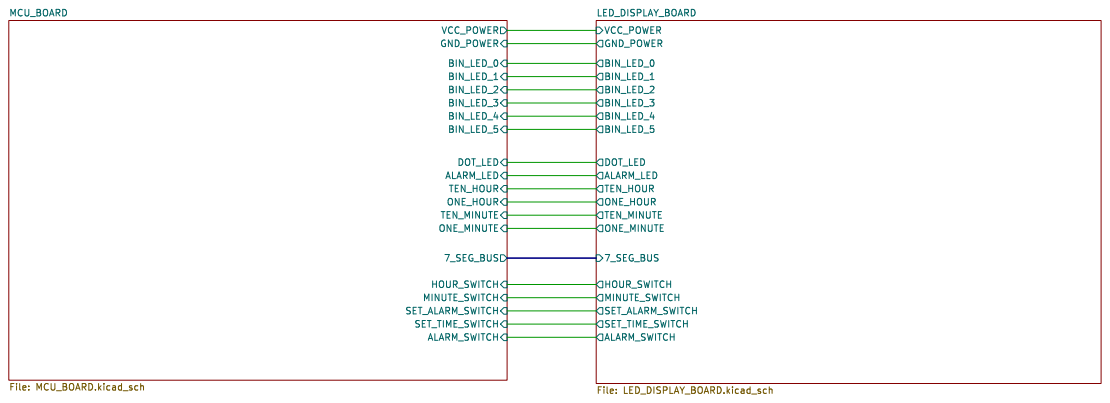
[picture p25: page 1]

Id: 1/3 Title: Military Time Clock

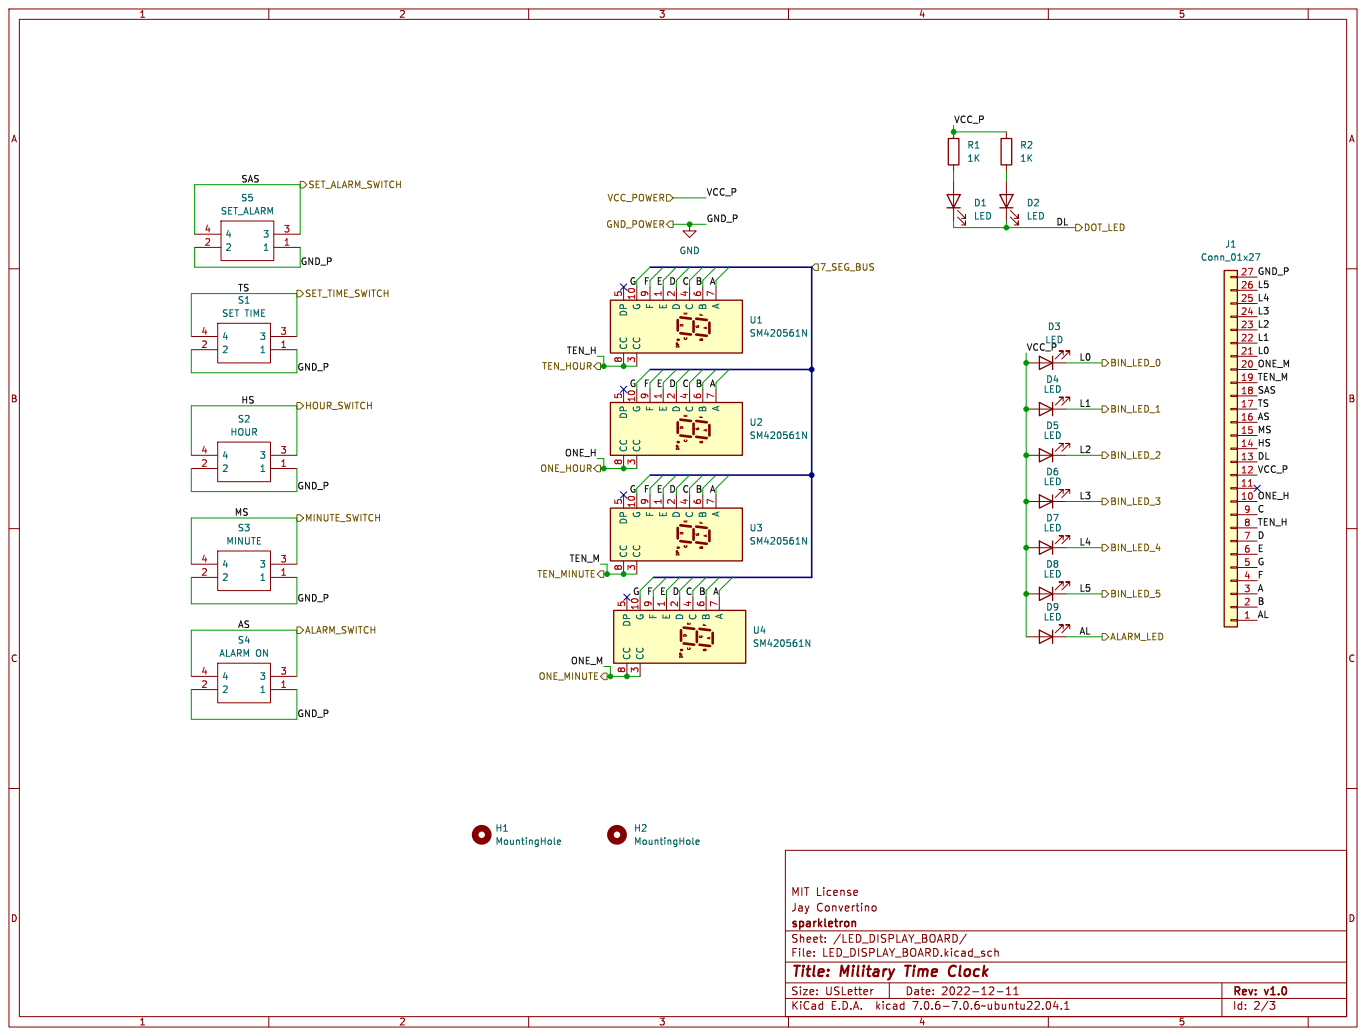
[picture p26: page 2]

sparkletron
File: LED_DISPLAY_BOARD.kicad_sch Sheet: /LED_DISPLAY_BOARD/
Id: 2/3 Title: Military Time Clock

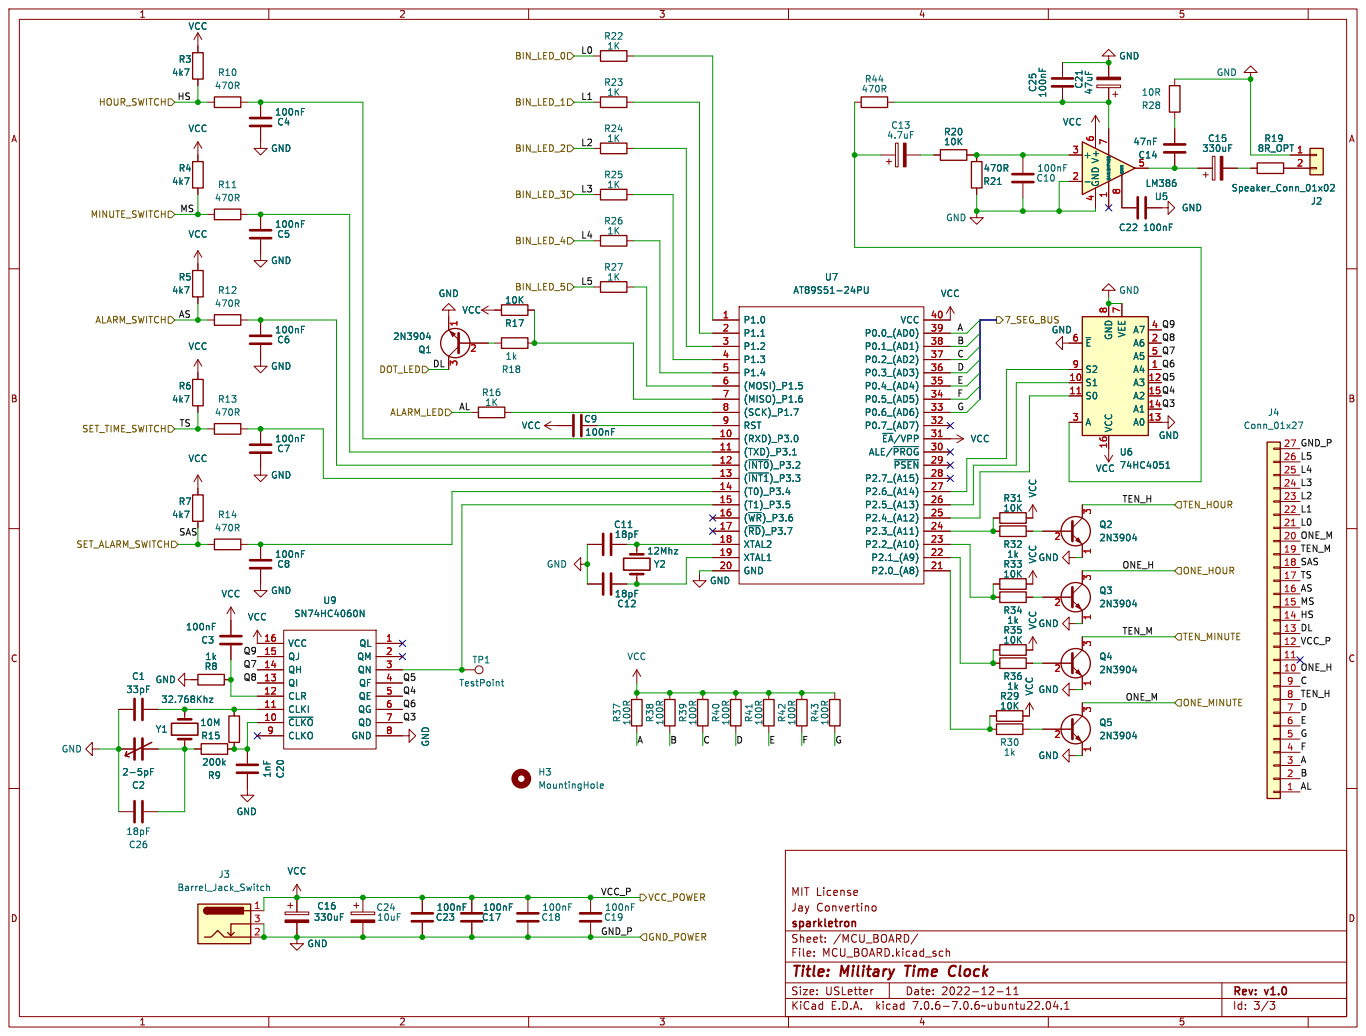
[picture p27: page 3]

sparkletron
File: MCU_BOARD.kicad_sch Sheet: /MCU_BOARD/
Id: 3/3 Title: Military Time Clock

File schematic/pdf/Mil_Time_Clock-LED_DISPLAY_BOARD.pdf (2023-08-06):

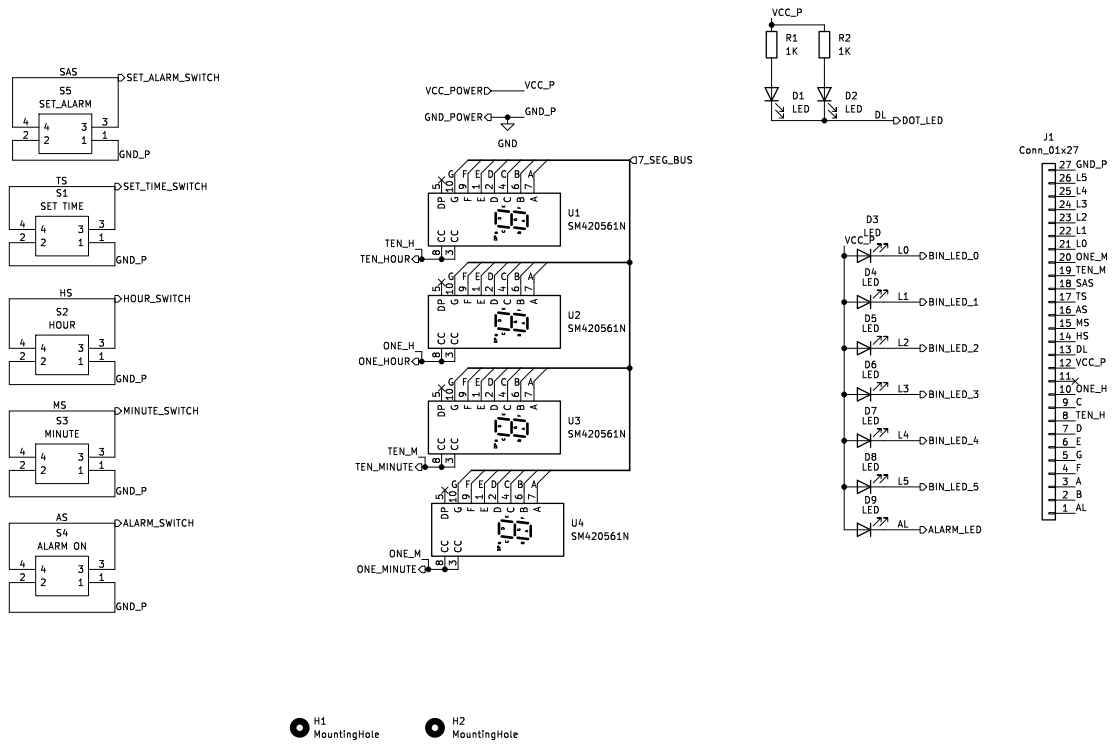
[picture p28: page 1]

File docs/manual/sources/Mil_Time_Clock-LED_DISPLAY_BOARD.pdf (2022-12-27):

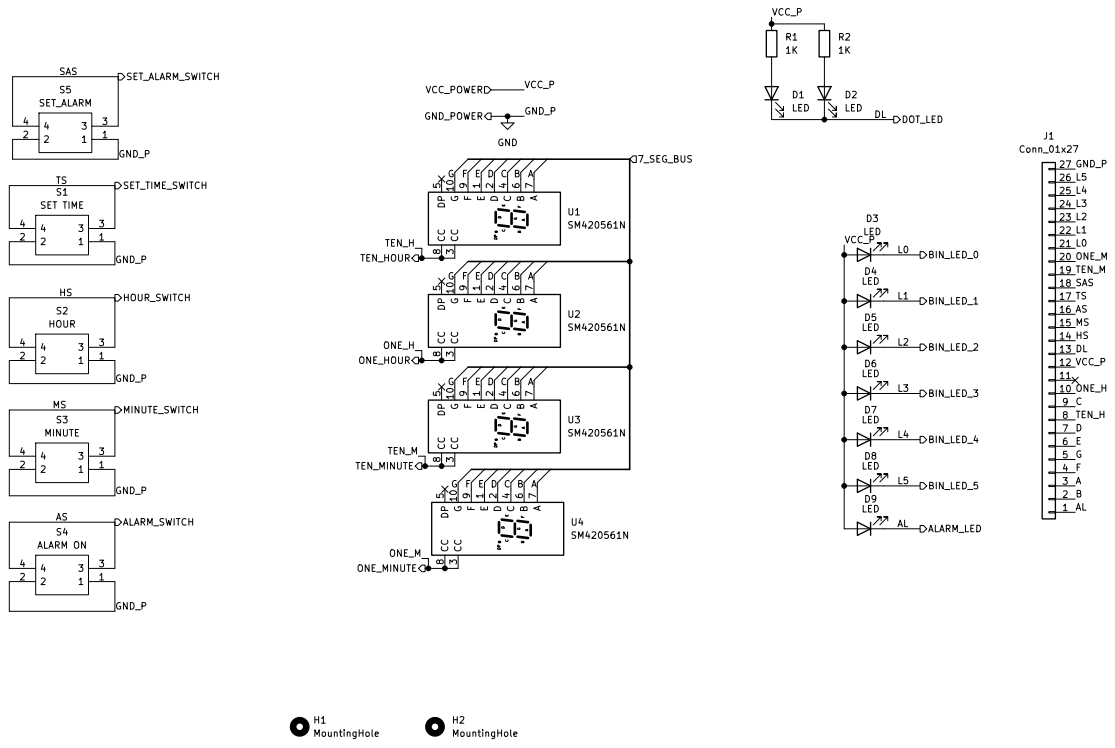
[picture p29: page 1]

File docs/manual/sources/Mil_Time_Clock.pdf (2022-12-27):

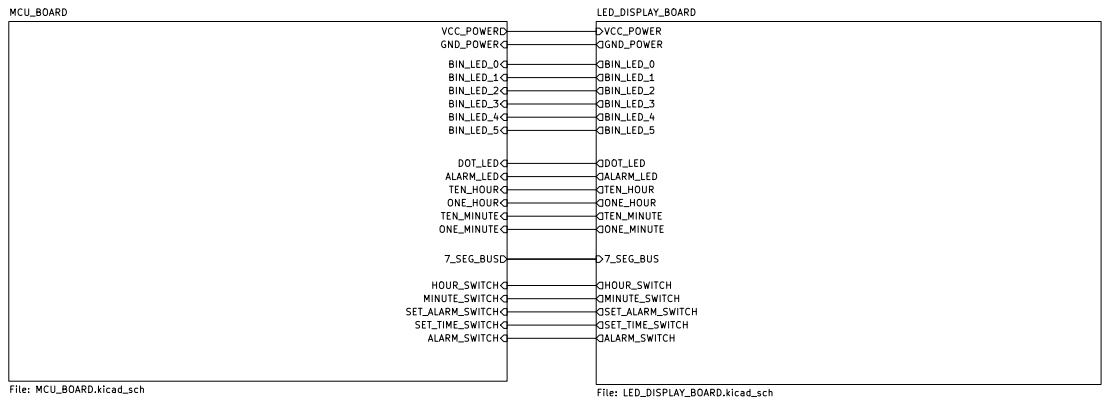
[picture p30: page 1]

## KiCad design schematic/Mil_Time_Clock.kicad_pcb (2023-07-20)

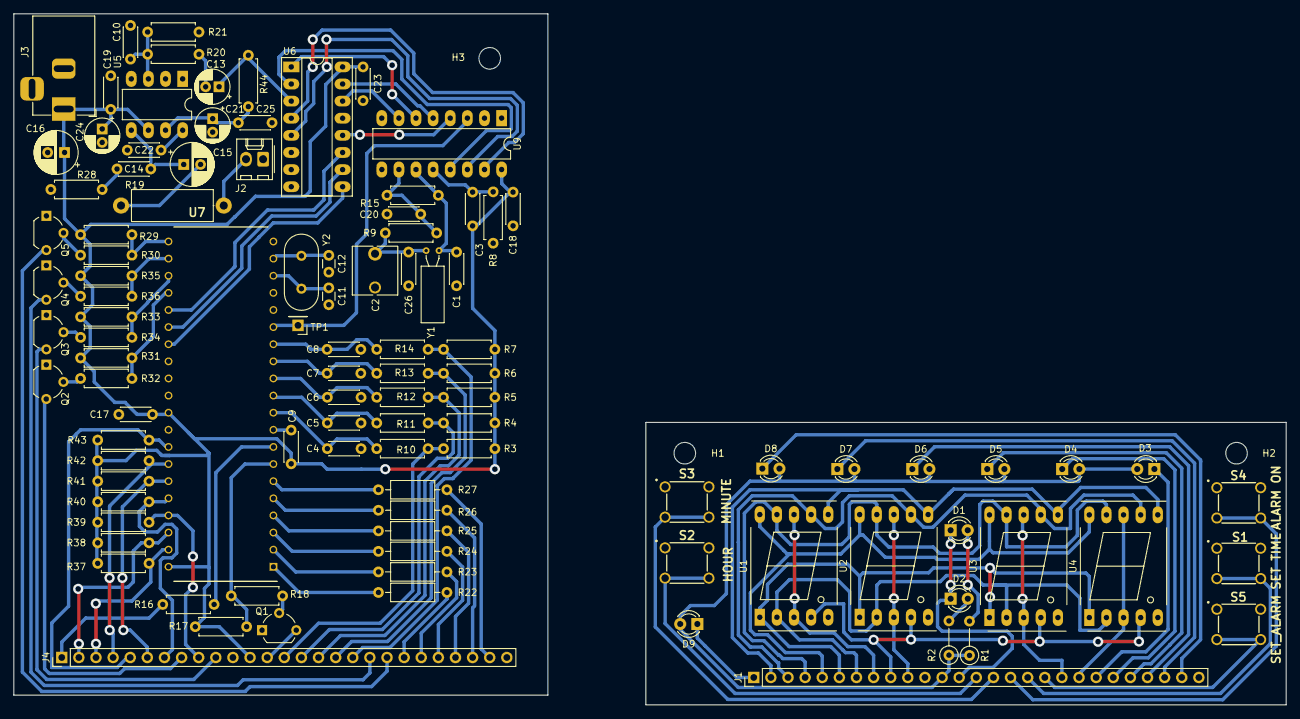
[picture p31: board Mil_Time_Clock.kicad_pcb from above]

Board: 2 copper layers, 188.8 x 102.5 mm, 107 parts (0 on the bottom side), 84 nets.

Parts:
C1: 47pF; C_Disc_D4.3mm_W1.9mm_P5.00mm
C2: 2-5pF; C_Rect_L7.0mm_W6.5mm_P5.00mm
C3, C4, C5, C6, C7, C8, C9, C10, C17, C18, C19, C22, C23, C25: 100nF; C_Disc_D4.3mm_W1.9mm_P5.00mm
C11, C12: 18pF; C_Disc_D3.0mm_W1.6mm_P2.50mm
C13: 4.7uF; CP_Radial_D5.0mm_P2.00mm
C14: 47nF; C_Disc_D4.3mm_W1.9mm_P5.00mm
C15, C16: 330uF; CP_Radial_D6.3mm_P2.50mm
C20: 1nF; C_Disc_D4.3mm_W1.9mm_P5.00mm
C21: 47uF; CP_Radial_D5.0mm_P2.00mm
C24: 10uF; CP_Radial_D5.0mm_P2.00mm
C26: 8pF; C_Disc_D4.3mm_W1.9mm_P5.00mm
D1, D2, D3, D4, D5, D6, D7, D8, D9: LED; LED_D3.0mm
H1, H2, H3: MountingHole; MountingHole_3.2mm_M3
J1, J4: Conn_01x27; PinHeader_1x27_P2.54mm_Vertical
J2: Speaker_Conn_01x02; Molex_KK-254_AE-6410-02A_1x02_P2.54mm_Vertical
J3: Barrel_Jack_Switch; BarrelJack_Horizontal
Q1, Q2, Q3, Q4, Q5: 2N3904; TO-92_Wide
R1, R2: 1K; R_Axial_DIN0207_L6.3mm_D2.5mm_P5.08mm_Vertical
R3, R4, R5, R6, R7: 4k7; R_Axial_DIN0207_L6.3mm_D2.5mm_P7.62mm_Horizontal
R8, R18, R30, R32, R34, R36: 1k; R_Axial_DIN0207_L6.3mm_D2.5mm_P7.62mm_Horizontal
R9: 200k; R_Axial_DIN0207_L6.3mm_D2.5mm_P7.62mm_Horizontal
R10, R11, R12, R13, R14, R21, R44: 470R; R_Axial_DIN0207_L6.3mm_D2.5mm_P7.62mm_Horizontal
R15: 10M; R_Axial_DIN0207_L6.3mm_D2.5mm_P7.62mm_Horizontal
R16: 1K; R_Axial_DIN0207_L6.3mm_D2.5mm_P7.62mm_Horizontal
R17, R20, R29, R31, R33, R35: 10K; R_Axial_DIN0207_L6.3mm_D2.5mm_P7.62mm_Horizontal
R19: 8R_OPT; R_Axial_DIN0414_L11.9mm_D4.5mm_P15.24mm_Horizontal
R22, R23, R24, R25, R26, R27: 1K; R_Axial_DIN0207_L6.3mm_D2.5mm_P10.16mm_Horizontal
R28: 10R; R_Axial_DIN0207_L6.3mm_D2.5mm_P7.62mm_Horizontal
R37, R38, R39, R40, R41, R42, R43: 100R; R_Axial_DIN0207_L6.3mm_D2.5mm_P7.62mm_Horizontal
S1: SET TIME; B3F1000
S2: HOUR; B3F1000
S3: MINUTE; B3F1000
S4: ALARM ON; B3F1000
S5: SET_ALARM; B3F1000
TP1: TestPoint; PinHeader_1x01_P2.54mm_Vertical
U1, U2, U3, U4: SM420561N; 7SegmentLED_LTS6760_LTS6780
U5: LM386; DIP-8_W7.62mm_LongPads
U6: 74HC4051; DIP-16_W7.62mm_Socket_LongPads
U7: AT89S51-24PU; DIP1556W56P254L5232H483Q40N
U9: SN74HC4060N; DIP-16_W7.62mm_LongPads
Y1: 32.768Khz; Crystal_C38-LF_D3.0mm_L8.0mm_Horizontal
Y2: 12Mhz; Crystal_HC49-U_Vertical

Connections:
/LED_DISPLAY_BOARD/A: J1.3, U1.7 (A), U2.7 (A), U3.7 (A), U4.7 (A)
/LED_DISPLAY_BOARD/AL: D9.1 (K), J1.1, J4.1, R16.1
/LED_DISPLAY_BOARD/AS: J1.16, J4.16, R5.1, R12.1, S4.3, S4.4
/LED_DISPLAY_BOARD/B: J1.2, U1.6 (B), U2.6 (B), U3.6 (B), U4.6 (B)
/LED_DISPLAY_BOARD/C: J1.9, U1.4 (C), U2.4 (C), U3.4 (C), U4.4 (C)
/LED_DISPLAY_BOARD/D: J1.7, U1.2 (D), U2.2 (D), U3.2 (D), U4.2 (D)
/LED_DISPLAY_BOARD/DL: D1.1 (K), D2.1 (K), J1.13, J4.13, Q1.3 (C)
/LED_DISPLAY_BOARD/E: J1.6, U1.1 (E), U2.1 (E), U3.1 (E), U4.1 (E)
/LED_DISPLAY_BOARD/F: J1.4, U1.9 (F), U2.9 (F), U3.9 (F), U4.9 (F)
/LED_DISPLAY_BOARD/G: J1.5, U1.10 (G), U2.10 (G), U3.10 (G), U4.10 (G)
/LED_DISPLAY_BOARD/HS: J1.14, J4.14, R3.1, R10.1, S2.3, S2.4
/LED_DISPLAY_BOARD/L0: D3.1 (K), J1.21, J4.21, R22.1
/LED_DISPLAY_BOARD/L1: D4.1 (K), J1.22, J4.22, R23.1
/LED_DISPLAY_BOARD/L2: D5.1 (K), J1.23, J4.23, R24.1
/LED_DISPLAY_BOARD/L3: D6.1 (K), J1.24, J4.24, R25.1
/LED_DISPLAY_BOARD/L4: D7.1 (K), J1.25, J4.25, R26.1
/LED_DISPLAY_BOARD/L5: D8.1 (K), J1.26, J4.26, R27.1
/LED_DISPLAY_BOARD/MS: J1.15, J4.15, R4.1, R11.2, S3.3, S3.4
/LED_DISPLAY_BOARD/ONE_H: J1.10, J4.10, Q3.3 (C), U2.3 (CC), U2.8 (CC)
/LED_DISPLAY_BOARD/ONE_M: J1.20, J4.20, Q5.3 (C), U4.3 (CC), U4.8 (CC)
/LED_DISPLAY_BOARD/SAS: J1.18, J4.18, R7.1, R14.1, S5.3, S5.4
/LED_DISPLAY_BOARD/TEN_H: J1.8, J4.8, Q2.3 (C), U1.3 (CC), U1.8 (CC)
/LED_DISPLAY_BOARD/TEN_M: J1.19, J4.19, Q4.3 (C), U3.3 (CC), U3.8 (CC)
/LED_DISPLAY_BOARD/TS: J1.17, J4.17, R6.1, R13.1, S1.3, S1.4
/MCU_BOARD/A: J4.3, R37.1, U7.39 (P0.0_(AD0))
/MCU_BOARD/B: J4.2, R38.1, U7.38 (P0.1_(AD1))
/MCU_BOARD/C: J4.9, R39.1, U7.37 (P0.2_(AD2))
/MCU_BOARD/D: J4.7, R40.1, U7.36 (P0.3_(AD3))
/MCU_BOARD/E: J4.6, R41.1, U7.35 (P0.4_(AD4))
/MCU_BOARD/F: J4.4, R42.1, U7.34 (P0.5_(AD5))
/MCU_BOARD/G: J4.5, R43.1, U7.33 (P0.6_(AD6))
/MCU_BOARD/Q3: U6.14 (A1), U9.7 (QD)
/MCU_BOARD/Q4: U6.15 (A2), U9.5 (QE)
/MCU_BOARD/Q5: U6.12 (A3), U9.4 (QF)
/MCU_BOARD/Q6: U6.1 (A4), U9.6 (QG)
/MCU_BOARD/Q7: U6.5 (A5), U9.14 (QH)
/MCU_BOARD/Q8: U6.2 (A6), U9.13 (QI)
/MCU_BOARD/Q9: U6.4 (A7), U9.15 (QJ)
GND: C1.1, C2.1, C4.2, C5.2, C6.2, C7.2, C8.2, C10.2, C11.1, C12.2, C16.2, C17.2, C18.2, C19.2, C20.1, C21.2, C22.1, C23.2, C24.2, C25.2, C26.2, J1.27, J2.1, J3.2, J3.3, J4.27, Q1.1 (E), Q2.1 (E), Q3.1 (E), Q4.1 (E), Q5.1 (E), R8.2, R21.1, R28.2, S1.1, S1.2, S2.1, S2.2, S3.1, S3.2, S4.1, S4.2, S5.1, S5.2, U5.2 (-), U5.4 (GND), U6.6 (~E), U6.7 (VEE), U6.8 (GND), U6.13 (A0), U7.20 (GND), U9.8 (GND)
unnamed: C2.2, C26.1, R9.1, Y1.1
unnamed: C13.2, R20.2
unnamed: C14.1, C15.1, U5.5
unnamed: C14.2, R28.1
unnamed: C15.2, R19.2
unnamed: C22.2, U5.8 (GAIN)
unnamed: D1.2 (A), R1.2
unnamed: D2.2 (A), R2.2
unnamed: J2.2, R19.1
unnamed: Q1.2 (B), R18.2
unnamed: Q2.2 (B), R32.2
unnamed: Q3.2 (B), R34.2
unnamed: Q4.2 (B), R36.2
unnamed: Q5.2 (B), R30.2
unnamed: C10.1, R20.1, R21.2, U5.3 (+)
unnamed: C21.1, C25.1, R44.1, U5.7 (BYPASS)
unnamed: C13.1, R44.2, U6.3 (A)
unnamed: U6.11 (S0), U7.25 (P2.4_(A12))
unnamed: U6.10 (S1), U7.26 (P2.5_(A13))
unnamed: U6.9 (S2), U7.27 (P2.6_(A14))
unnamed: R17.2, R18.1, U7.7 ((MISO)_P1.6)
unnamed: R27.2, U7.6 ((MOSI)_P1.5)
unnamed: C4.1, R10.2, U7.10 ((RXD)_P3.0)
unnamed: R16.2, U7.8 ((SCK)_P1.7)
unnamed: C8.1, R14.2, U7.14 ((T0)_P3.4)
unnamed: TP1.1, U7.15 ((T1)_P3.5), U9.3 (QN)
unnamed: C5.1, R11.1, U7.11 ((TXD)_P3.1)
unnamed: C6.1, R12.2, U7.12 ((~INT0)_P3.2)
unnamed: C7.1, R13.2, U7.13 ((~INT1)_P3.3)
unnamed: R22.2, U7.1 (P1.0)
unnamed: R23.2, U7.2 (P1.1)
unnamed: R24.2, U7.3 (P1.2)
unnamed: R25.2, U7.4 (P1.3)
unnamed: R26.2, U7.5 (P1.4)
unnamed: R29.1, R30.1, U7.21 (P2.0_(A8))
unnamed: R35.1, R36.1, U7.22 (P2.1_(A9))
unnamed: R33.1, R34.1, U7.23 (P2.2_(A10))
unnamed: R31.1, R32.1, U7.24 (P2.3_(A11))
unnamed: C9.2, U7.9 (RST)
unnamed: C12.1, U7.19 (XTAL1), Y2.1
unnamed: C11.2, U7.18 (XTAL2), Y2.2
unnamed: C1.2, R15.2, U9.11 (CLKI), Y1.2
unnamed: C3.2, R8.1, U9.12 (CLR)
unnamed: C20.2, R9.2, R15.1, U9.10 (~CLKO)
VCC: C3.1, C9.1, C16.1, C17.1, C18.1, C19.1, C23.1, C24.1, D3.2 (A), D4.2 (A), D5.2 (A), D6.2 (A), D7.2 (A), D8.2 (A), D9.2 (A), J1.12, J3.1, J4.12, R1.1, R2.1, R3.2, R4.2, R5.2, R6.2, R7.2, R17.1, R29.2, R31.2, R33.2, R35.2, R37.2, R38.2, R39.2, R40.2, R41.2, R42.2, R43.2, U5.6 (V+), U6.16 (VCC), U7.31 (~EA/VPP), U7.40 (VCC), U9.16 (VCC)

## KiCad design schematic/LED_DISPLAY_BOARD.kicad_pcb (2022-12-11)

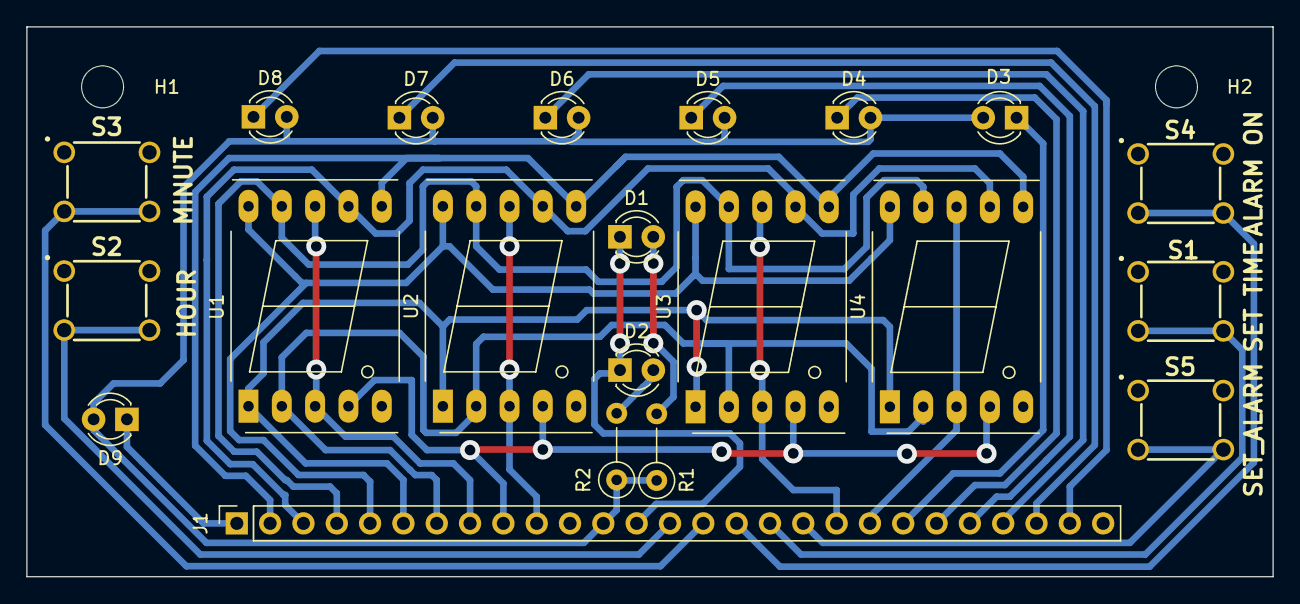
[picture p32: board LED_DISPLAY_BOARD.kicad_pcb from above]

Board: 2 copper layers, 95.0 x 41.9 mm, 23 parts (0 on the bottom side), 28 nets.

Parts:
D1, D2, D3, D4, D5, D6, D7, D8, D9: LED; LED_D3.0mm
H1, H2: MountingHole; MountingHole_3.2mm_M3
J1: Conn_01x27; PinSocket_1x27_P2.54mm_Vertical
R1, R2: 220R; R_Axial_DIN0207_L6.3mm_D2.5mm_P5.08mm_Vertical
S1: SET TIME; B3F1000
S2: HOUR; B3F1000
S3: MINUTE; B3F1000
S4: ALARM ON; B3F1000
S5: SET_ALARM; B3F1000
U1, U2, U3, U4: SM420561N; 7SegmentLED_LTS6760_LTS6780

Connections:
/LED_DISPLAY_BOARD/A: J1.3, U1.7 (A), U2.7 (A), U3.7 (A), U4.7 (A)
/LED_DISPLAY_BOARD/AL: D9.1 (K), J1.1
/LED_DISPLAY_BOARD/AS: J1.16, S4.3, S4.4
/LED_DISPLAY_BOARD/B: J1.2, U1.6 (B), U2.6 (B), U3.6 (B), U4.6 (B)
/LED_DISPLAY_BOARD/C: J1.9, U1.4 (C), U2.4 (C), U3.4 (C), U4.4 (C)
/LED_DISPLAY_BOARD/D: J1.7, U1.2 (D), U2.2 (D), U3.2 (D), U4.2 (D)
/LED_DISPLAY_BOARD/DL: D1.1 (K), D2.1 (K), J1.13
/LED_DISPLAY_BOARD/E: J1.6, U1.1 (E), U2.1 (E), U3.1 (E), U4.1 (E)
/LED_DISPLAY_BOARD/F: J1.4, U1.9 (F), U2.9 (F), U3.9 (F), U4.9 (F)
/LED_DISPLAY_BOARD/G: J1.5, U1.10 (G), U2.10 (G), U3.10 (G), U4.10 (G)
/LED_DISPLAY_BOARD/HS: J1.14, S2.3, S2.4
/LED_DISPLAY_BOARD/L0: D3.1 (K), J1.21
/LED_DISPLAY_BOARD/L1: D4.1 (K), J1.22
/LED_DISPLAY_BOARD/L2: D5.1 (K), J1.23
/LED_DISPLAY_BOARD/L3: D6.1 (K), J1.24
/LED_DISPLAY_BOARD/L4: D7.1 (K), J1.25
/LED_DISPLAY_BOARD/L5: D8.1 (K), J1.26
/LED_DISPLAY_BOARD/MS: J1.15, S3.3, S3.4
/LED_DISPLAY_BOARD/ONE_H: J1.10, U2.3 (CC), U2.8 (CC)
/LED_DISPLAY_BOARD/ONE_M: J1.20, U4.3 (CC), U4.8 (CC)
/LED_DISPLAY_BOARD/SAS: J1.18, S5.3, S5.4
/LED_DISPLAY_BOARD/TEN_H: J1.8, U1.3 (CC), U1.8 (CC)
/LED_DISPLAY_BOARD/TEN_M: J1.19, U3.3 (CC), U3.8 (CC)
/LED_DISPLAY_BOARD/TS: J1.17, S1.3, S1.4
GND: J1.27, S1.1, S1.2, S2.1, S2.2, S3.1, S3.2, S4.1, S4.2, S5.1, S5.2
unnamed: D1.2 (A), R1.2
unnamed: D2.2 (A), R2.2
VCC: D3.2 (A), D4.2 (A), D5.2 (A), D6.2 (A), D7.2 (A), D8.2 (A), D9.2 (A), J1.12, R1.1, R2.1

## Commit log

2022-12-11 initial commit for v1.0.0
    [Board_Geoms_403d.iam, Board_Geoms_bc71.iam, C10_C_Disc_D30mm_W20mm_P250mm_fe13f3843ca1.ipt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]
2022-12-16 updated case for 3d printing
    [Case_Front.ipt, Case_Front.stl, case.0014.iam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]
2022-12-21 adjusted a trace, since ISOPRO did not pick up on it being 12 mil away.
    [MCU_BOARD.kicad_pcb, Mil_Time_Clock.kicad_pcb]
2022-12-21 whoops, wrong trace, now the 12 mil trace is adjusted
    [MCU_BOARD.kicad_pcb, Mil_Time_Clock.kicad_pcb]
2022-12-21 changed cap values to fix issues with clock crystial, was off by +2 hz
    [MCU_BOARD.kicad_sch, Mil_Time_Clock.kicad_sch]
2022-12-21 tweaked the schematic, now the trimmer cap + start value adds up to the other cap of 47 pf for balance.
    [MCU_BOARD.kicad_sch, Mil_Time_Clock.kicad_sch]
2022-12-27 updated BOM with all part numbers and costs, at 5.11 they are not cheap in small runs.
    [Case_Front.0026.ipt, Mil_Time_Clock_BOM.csv, case.0015.iam]
2023-01-13 added padding resistor to halve the speaker volume and deal with some noise issues in some units. Noise is originating from the 7 segment LED data lines. It runs at about 1khz so this makes sense, wi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
    [MCU_BOARD.kicad_pcb, MCU_BOARD.kicad_sch, Mil_Time_Clock.kicad_pcb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]
2023-01-16 mit license update
    [LED_DISPLAY_BOARD.kicad_sch, MCU_BOARD.kicad_sch, Mil_Time_Clock.kicad_sch]
2023-04-24 fixed ground issue
    [MCU_BOARD.kicad_pcb, Mil_Time_Clock.kicad_pcb]
2023-07-18 bad state, but wanted to document changes to the v1 cap values. Need to fix PCB, it got messed up for some odd reason.
    [MCU_BOARD.kicad_pcb, MCU_BOARD.kicad_sch]
2023-07-20 added resistor from input to bypass of lm386. When the alarm is off the input is ground, this reduces noise issues to about nothing. Updated PCB.
    [LED_DISPLAY_BOARD.kicad_sch, MCU_BOARD.kicad_pcb, MCU_BOARD.kicad_sch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]
2023-08-06 adjusted cap values for best possible +/- 3 hz adjustment around 2048 clock output. This produces the best clock so far and allows for finer tuning at the lower frequencies.
    [MCU_BOARD.kicad_sch, Mil_Time_Clock_BOM.csv]
